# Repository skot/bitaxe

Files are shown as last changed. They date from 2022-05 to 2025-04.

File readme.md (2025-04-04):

# Bitaxe hardware repository has split into model specific repos and moved to [bitaxeorg](https://github.com/bitaxeorg)
```
Open Source is Intrinsic to Bitcoin
```
# The bitaxeUltra
bitaxe is a fully open source hardware Bitcoin ASIC miner. Ultra is the 3rd major revision of the bitaxe that now includes the BM1366 ASIC from the S19XP

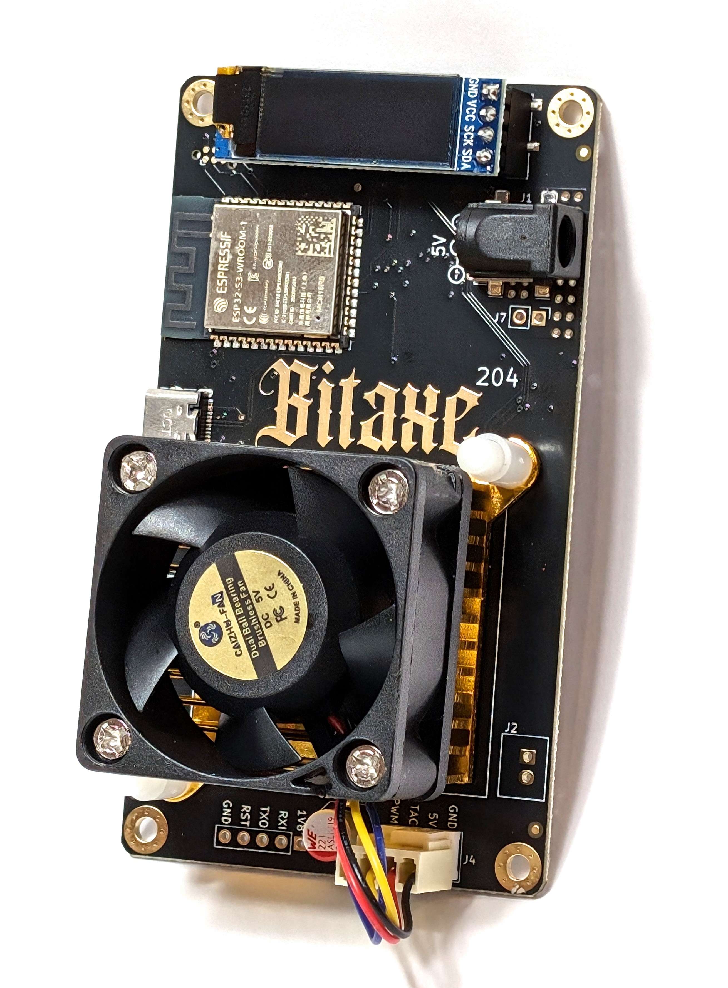
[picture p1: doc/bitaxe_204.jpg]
bitaxeUltra assembled


## Goals
- **Standalone**: can mine directly to your pool over WiFi. No External computer needed.
- **Embedded**: low cost, low maintenance, high availability, high reliability, low power.
- **ASIC**: based on the very, very efficient BM1366 from Bitmain.
- **Versatile**: solo/pool mining, autotune power/heat/efficiency.
- **Open Source**: All design files are provided.

## Features
- **ESP32-S3-WROOM-1** wifi microcontroller on board
- **TI TPS40305** buck regulator steps down the 5V input to power the BM1366
- **Maxim DS4432U+** current DAC digitally adjusts the BM1366 core voltage from 0.04V to 2.4V
- **TI INA260** power meter measures the input voltage and current of the miner
- **Microchip EMC2101** PWM controls the fan and monitors tach output. BM1366 doesn't support die temp, but we have it placed super close to the ASIC so we can use the internal temp feature.
- 0.91" **SSD1306 OLED** I2C Display Module 

## BM1366
- The BM1366 is a undocumented SHA256 mining ASIC from Bitmain. It's used in the Antminer S19XP and the S19k Pro
- Bitmain claims the BM1366 has 0.021J/GH efficiency
- The BM1366 is available (new) for around $15 each in small quantities.
- The BM1366 has a different footprint and pinout from the BM1397 and BM1387 in previous bitaxe.
- The BM1366 appears to roll more than just the nonce on the chip. This is great news, because it allows much longer serial chains of ASICs and new work doesn't need to be sent as often.

## Current Status
- Bitaxe Ultra 204 hardware has been verified and is working nicely!
- Be sure to check the [issues](https://github.com/skot/bitaxe/issues) for known bugs, reworks and errata.
- This is an _advanced_ build! You can do it, but if you're not looking for a project, it might be best to buy one pre-assembled from one of the many sellers.

## Hardware
- Order PCBs from your favorite PCB shop, like [JLCPCB](https://jlcpcb.com), [SeeedStudio](https://www.seeedstudio.com/fusion_pcb.html), or [PCBWay](https://www.pcbway.com)
    - Gerbers are in the `Manufacturing Files` dir. PCBs are 4-layer, 6mil trace/space and 0.3mm hole compatible. 1oz outer / 0.5oz inner layer thickness works well.
    - Make sure to order stencils too. These are the "paste" layers in the gerbers folder. one for top and one for bottom.
- All PCB parts except the ASIC are available from [DigiKey](https://www.digikey.com/en/products) and others. You can find Digikey part numbers on the DK tab of the BOM
- [BM1366 ASIC from NBTC on AliExpress](https://www.aliexpress.us/item/3256804709142138.html). I got the "AG" variant. Not really sure what the difference is -- "AL" works also.
- [40x40mm heatsink and 5V fan](https://www.aliexpress.com/item/2251832861666365.html) from a random AliExpress seller. The fans are crap, but the heatsinks are good. **make sure** to use a good quality thermal compound between the heatsink and ASIC!
- Upgrade your fan with the [Noctua NF-A4x20](https://www.amazon.com/Noctua-NF-A4x20-5V-PWM-Premium-Quality/dp/B071FNHVXN) 5V 4-Pin fan for a much more pleasant experience.
	- Get some longer mounting screws for the 20mm thick fan vs the 10mm thick fan that comes with the heatsink: [M3x25mm Flat Head Wood Self Tapping screws](https://www.amazon.com/dp/B08W5DQ23J)
- Supports 0.91" SSD1306-based I2C OLED Module. [Example Amazon seller](https://www.amazon.com/gp/product/B08ZY4YBHL)
- [KiCad 7](https://www.kicad.org) design files

## Software
- The [ESP-Miner](https://github.com/skot/ESP-Miner) firmware used for the BM1397-based bitaxe has been adapted for the BM1366 and the current main branch can support both.

## Cooling
- You **must** have active cooling on the bitaxe. 
- The Bitaxe has a connector for a 5V fan. 40x40mm fans work nicely with the suggested heatsink
- The fan connector uses the 4-pin standard:
	- 2 pins are for 5V power
	- pin 3 is fan speed sensing
	- pin 4 is fan speed control (PWM) 

## Power Supply Requirements
- **5V DC Only!** Anything else will damage the Bitaxe. Be careful and double-check your power supply is 5V. Many other voltage power supplies use the same connector.
- The Bitaxe needs 15W. Be aware that many power supplies _cannot_ deliver 5V at the listed power. It is best to pick an overrated power supply. 25W (5V, 5A) PSUs have been working well for people.
- The Bitaxe uses a 5.5x2.1mm, center-positive barrel jack.

### ESP32 Programming Requirements
- As of the bitaxeUltra, all ESP32 programming is done through a USB-C cable and connector on the bitaxe. See [ESP-Miner](https://github.com/skot/ESP-Miner) for more details.

## Building
- Check out [building.md](building.md) for PCB ordering tips
- Check out [assembly.md](assembly.md) for assembly tips

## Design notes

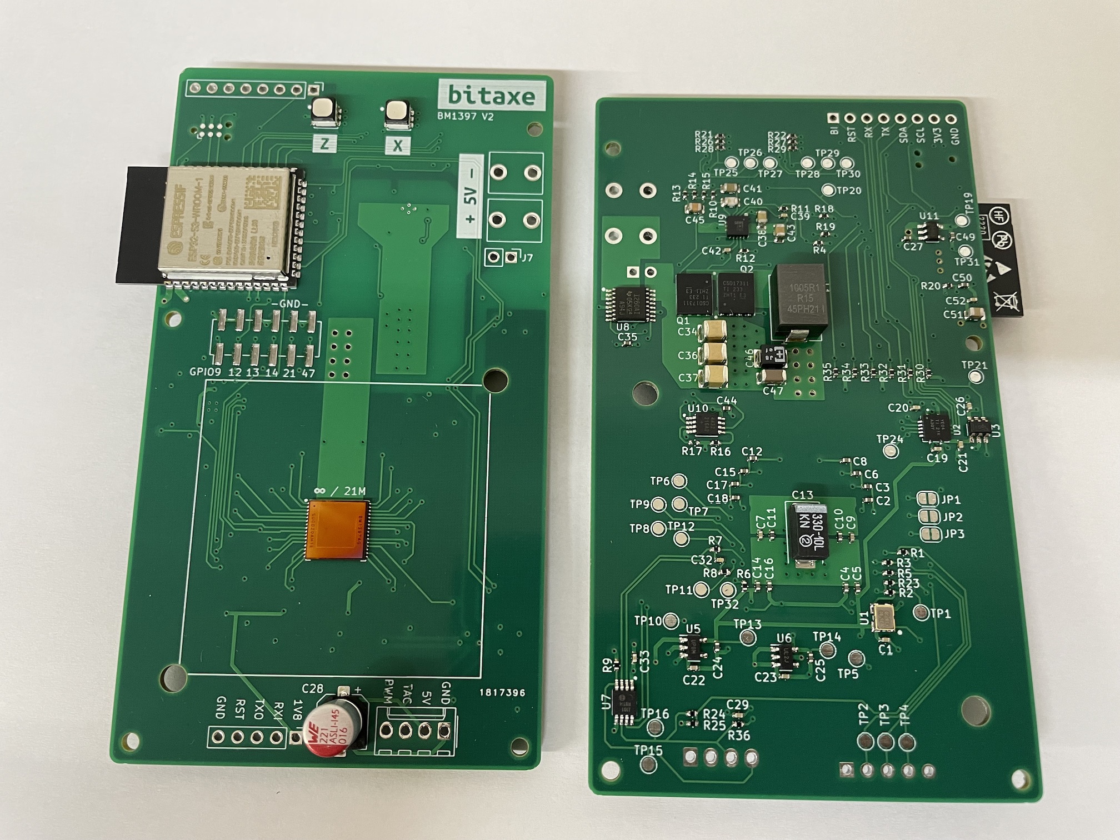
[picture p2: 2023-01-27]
doc/v2_both_sides.jpg

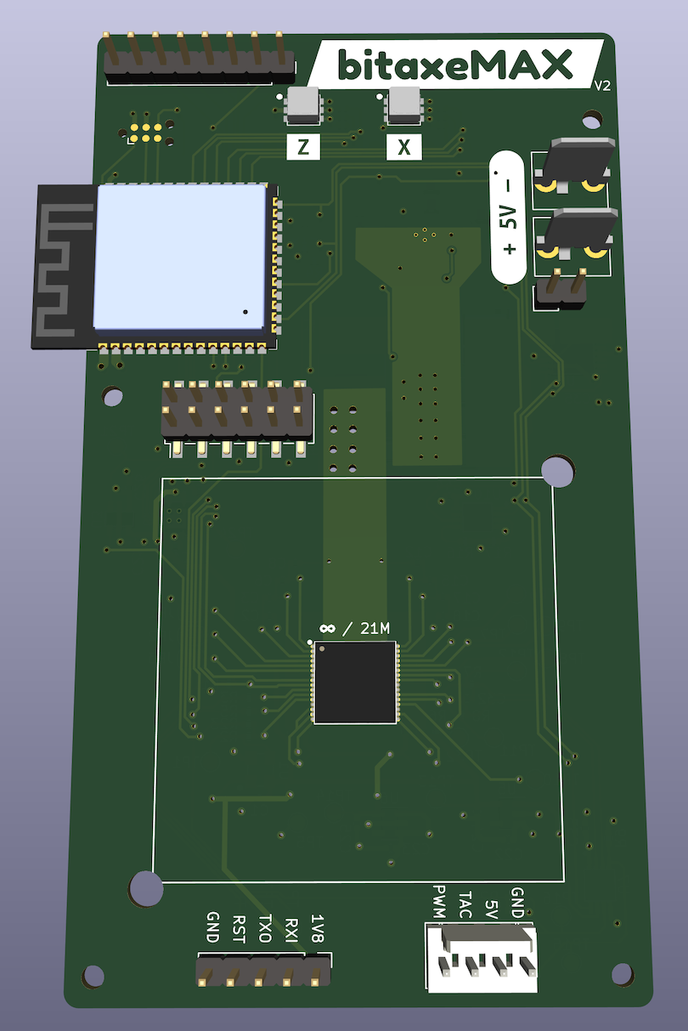
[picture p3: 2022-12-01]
doc/front.png

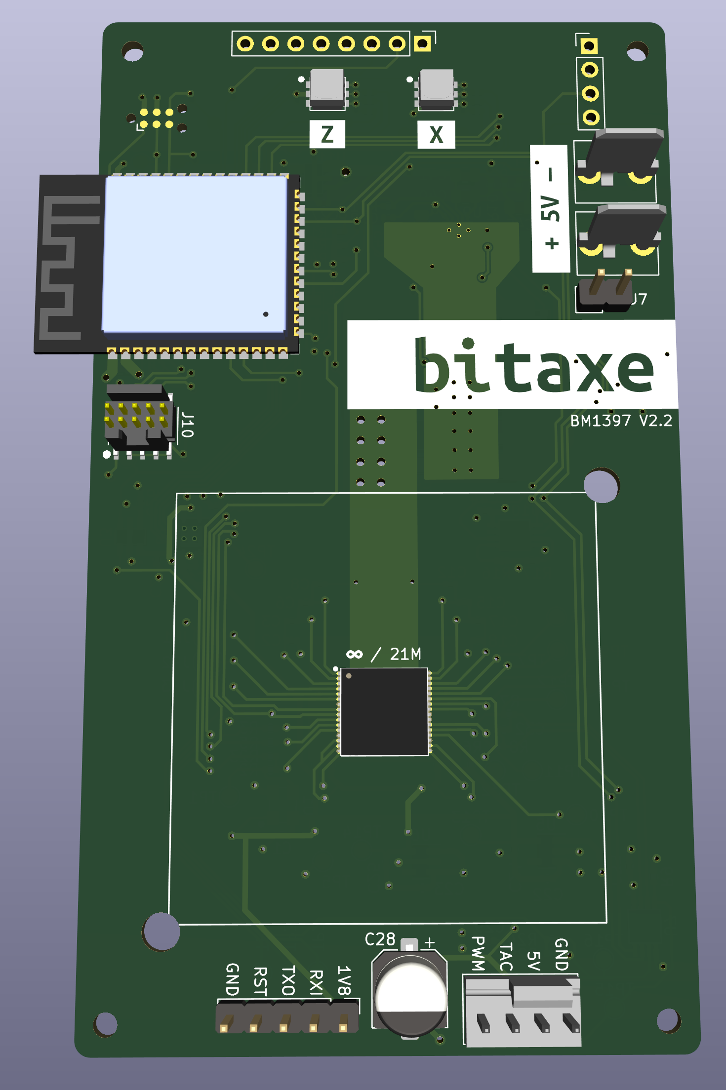
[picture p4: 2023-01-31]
doc/render.png

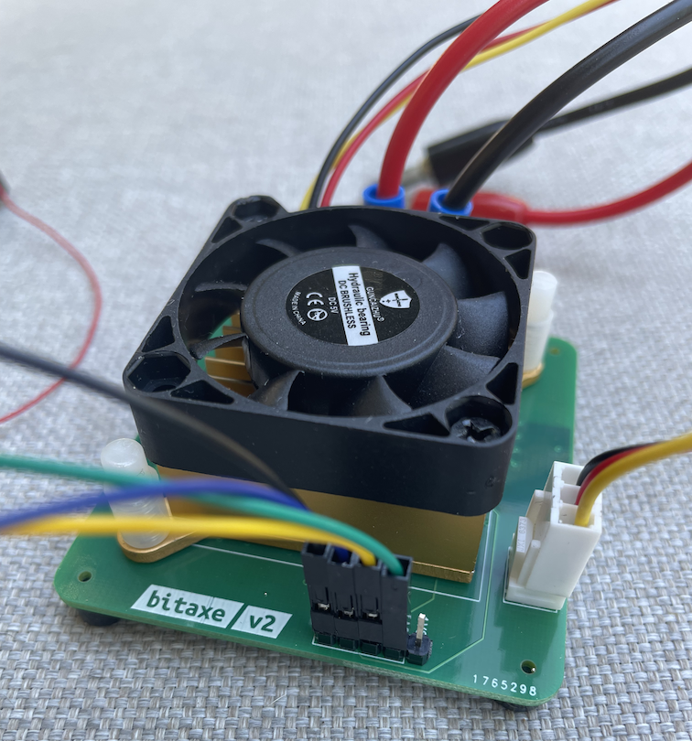
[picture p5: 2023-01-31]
doc/bitaxe.png

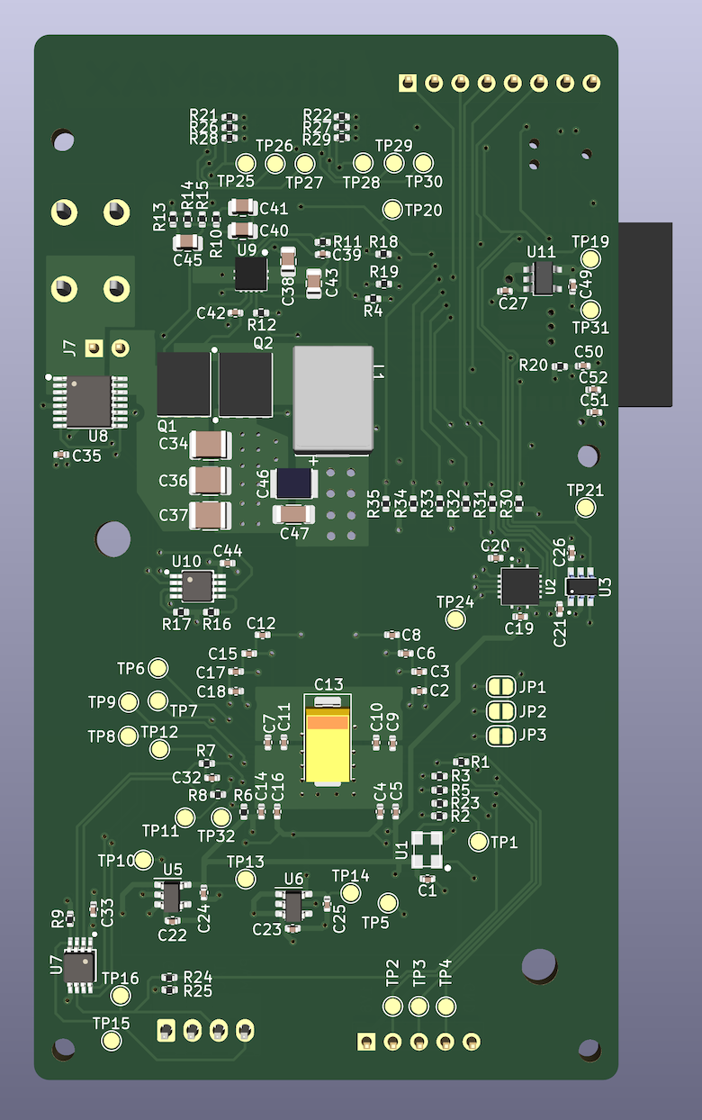
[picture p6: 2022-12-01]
doc/back.png

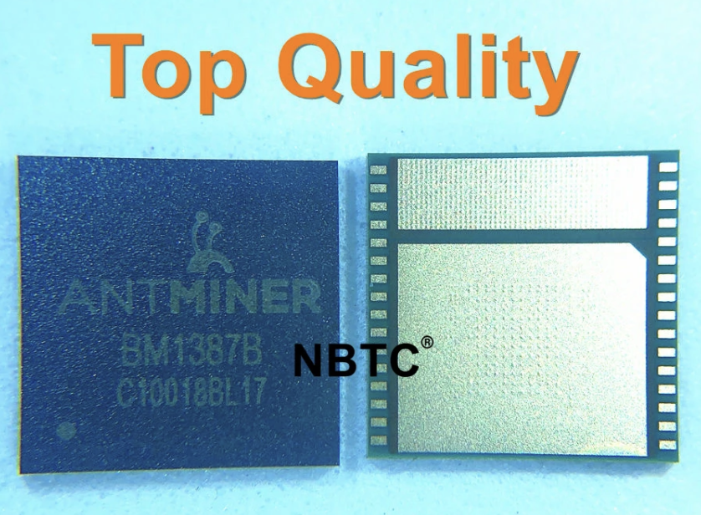
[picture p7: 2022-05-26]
doc/bm1387.png

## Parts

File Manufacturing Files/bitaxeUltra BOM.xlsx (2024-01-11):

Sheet: BOM
Qty | Ref Des | Value | DK | PARTNO | DNP
9 | C1, C7, C9, C19, C20, C29, C33, C42, C52 | 0.1uF | 1292-1639-1-ND | 0402X104K100CT
23 | C2, C3, C4, C5, C6, C8, C10, C11, C12, C14, C15, C16, C17, C18, C21, C22, C23, C24, C25, C27, C35, C44, C49 | 1uF | 587-5514-1-ND | EMK105BJ105MV-F
1 | C13 | 330uF | 718-1028-1-ND | 293D337X9010E2TE3
1 | C28 | 220uF | 732-8422-1-ND | 865080345012
2 | C30, C31 | 6.8pF | 399-C0402C689C5GAC7867CT-ND | C0402C689C5GAC7867
3 | C34, C36, C37 | 47uF | 490-6539-1-ND | GRM32ER61C476KE15L
1 | C38 | 1uF | 1276-6471-1-ND | CL21B105KOFNNNG
1 | C39 | 3.3nF | 1276-1552-1-ND | CL05B332KB5NNNC
1 | C40 | 180pF | 311-1114-1-ND | CC0805JRNPO9BN181
1 | C41 | 1.5nF | 311-1128-1-ND | CC0805KRX7R9BB152
2 | C43, C51 | 10uF | 1276-1096-1-ND | CL21A106KOQNNNE
1 | C45 | 470pF | 1292-1580-1-ND | 0805B471K500CT
1 | C46 | 220uF | P16200CT-ND | 2R5TPE220MAFB
1 | C47 | 100uF | 445-6008-1-ND | C3216X5R0J107M160AB
1 | D1 | SS310 | SK310A-LTPMSCT-ND | SK310A-LTP
1 | J1 | 54-00164 | 839-54-00164CT-ND | 54-00164
1 | J2 | Conn_01x02 | 455-B2B-XH-A-ND | B2B-XH-A
1 | J4 | Conn_01x04 | WM4330-ND | 0470531000
1 | J8 | USB_C_Receptacle_USB2.0 | 2073-USB4105-GF-ACT-ND | USB4105-GF-A
1 | L1 | 150nH | 513-1568-1-ND | FP1005R1-R15-R
2 | Q1, Q2 | CSD17311Q5 | 296-27625-1-ND | CSD17311Q5
1 | Q4 | 2N7002K | 2N7002KWCT-ND | 2N7002KW
5 | R1, R4, R6, R7, R9 | 10k | 311-10KJRCT-ND | RC0402JR-0710KL
1 | R2 | 5.6k | 13-RC0402FR-135K6LCT-ND | RC0402FR-135K6L
2 | R3, R5 | 5.1k | RMCF0402JT5K10CT-ND | RMCF0402JT5K10
1 | R8 | 1M | 311-1.00MLRCT-ND | RC0402FR-071ML
1 | R10 | 3.83k | 311-3.83KLRCT-ND | RC0402FR-073K83L
1 | R12 | 4.12k | RMCF0402FT4K12CT-ND | RMCF0402FT4K12
1 | R13 | 1.33k | 311-1.33KLRCT-ND | RC0402FR-071K33L
1 | R14 | 4.99k | 311-4.99KLRCT-ND | RC0402FR-074K99L
1 | R15 | 3.32k | 311-3.32KLRCT-ND | RC0402FR-073K32L
1 | R16 | 80.6k | 311-80.6KLRCT-ND | RC0402FR-0780K6L
2 | SW1, SW2 | GT-TC029B-H025-L1N | 2449-CS1213AGF260CT-ND | CS1213AGF260
1 | U1 | 25MHz | 1908-O250-JO32-B-1V3-1-T1-LFCT-ND | O 25,0-JO32-B-1V3-1-T1-LF
1 | U2 | TXB0104RGYR | 296-21930-1-ND | TXB0104RGYR
1 | U5 | MCP1824T-1802E | MCP1824T-1802E/OTCT-ND | MCP1824T-1802E/OT
1 | U6 | MCP1824T-0802E | MCP1824T-0802E/OTCT-ND | MCP1824T-0802E/OT
1 | U7 | EMC2101 | EMC2101-R-ACZL-CT-ND | EMC2101-R-ACZL-TR
1 | U8 | INA260 | 296-45218-5-ND | INA260AIPW
1 | U9 | TPS40305 | 296-37445-1-ND | TPS40305DRCR
1 | U10 | DS4432U+ | DS4432U+-ND | DS4432U+
1 | U11 | RT9080-33GJ5 | 1028-1509-1-ND | RT9080-33GJ5
1 | U12 | ESP32-S3-WROOM-1 | 1965-ESP32-S3-WROOM-1-N16R8CT-ND | ESP32-S3-WROOM-1-N16R8
1 | U14 | BM1366_mode1
1 | Y1 | 32.768kHz | 728-1074-1-ND | SC32S-7PF20PPM
1 | J9 | Conn_01x04 | S5596-ND | NPTC041KFXC-RC

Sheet: DK Order
Qty | Ref Des | DK
9 | C1, C7, C9, C19, C20, C29, C33, C42, C52 | 1292-1639-1-ND
23 | C2, C3, C4, C5, C6, C8, C10, C11, C12, C14, C15, C16, C17, C18, C21, C22, C23, C24, C25, C27, C35, C44, C49 | 587-5514-1-ND
1 | C13 | 718-1028-1-ND
1 | C28 | 732-8422-1-ND
2 | C30, C31 | 399-C0402C689C5GAC7867CT-ND
3 | C34, C36, C37 | 490-6539-1-ND
1 | C38 | 1276-6471-1-ND
1 | C39 | 1276-1552-1-ND
1 | C40 | 311-1114-1-ND
1 | C41 | 311-1128-1-ND
2 | C43, C51 | 1276-1096-1-ND
1 | C45 | 1292-1580-1-ND
1 | C46 | P16200CT-ND
1 | C47 | 445-6008-1-ND
1 | D1 | SK310A-LTPMSCT-ND
1 | J1 | 839-54-00164CT-ND
1 | J2 | 455-B2B-XH-A-ND
1 | J4 | WM4330-ND
1 | J8 | 2073-USB4105-GF-ACT-ND
1 | L1 | 513-1568-1-ND
2 | Q1, Q2 | 296-27625-1-ND
1 | Q4 | 2N7002KWCT-ND
5 | R1, R4, R6, R7, R9 | 311-10KJRCT-ND
1 | R2 | 13-RC0402FR-135K6LCT-ND
2 | R3, R5 | RMCF0402JT5K10CT-ND
1 | R8 | 311-1.00MLRCT-ND
1 | R10 | 311-3.83KLRCT-ND
1 | R12 | RMCF0402FT4K12CT-ND
1 | R13 | 311-1.33KLRCT-ND
1 | R14 | 311-4.99KLRCT-ND
1 | R15 | 311-3.32KLRCT-ND
1 | R16 | 311-80.6KLRCT-ND
2 | SW1, SW2 | 2449-CS1213AGF260CT-ND
1 | U1 | 1908-O250-JO32-B-1V3-1-T1-LFCT-ND
1 | U2 | 296-21930-1-ND
1 | U5 | MCP1824T-1802E/OTCT-ND
1 | U6 | MCP1824T-0802E/OTCT-ND
1 | U7 | EMC2101-R-ACZL-CT-ND
1 | U8 | 296-45218-5-ND
1 | U9 | 296-37445-1-ND
1 | U10 | DS4432U+-ND
1 | U11 | 1028-1509-1-ND
1 | U12 | 1965-ESP32-S3-WROOM-1-N16R8CT-ND
1 | U14
1 | Y1 | 728-1074-1-ND
1 | J9 | S5596-ND

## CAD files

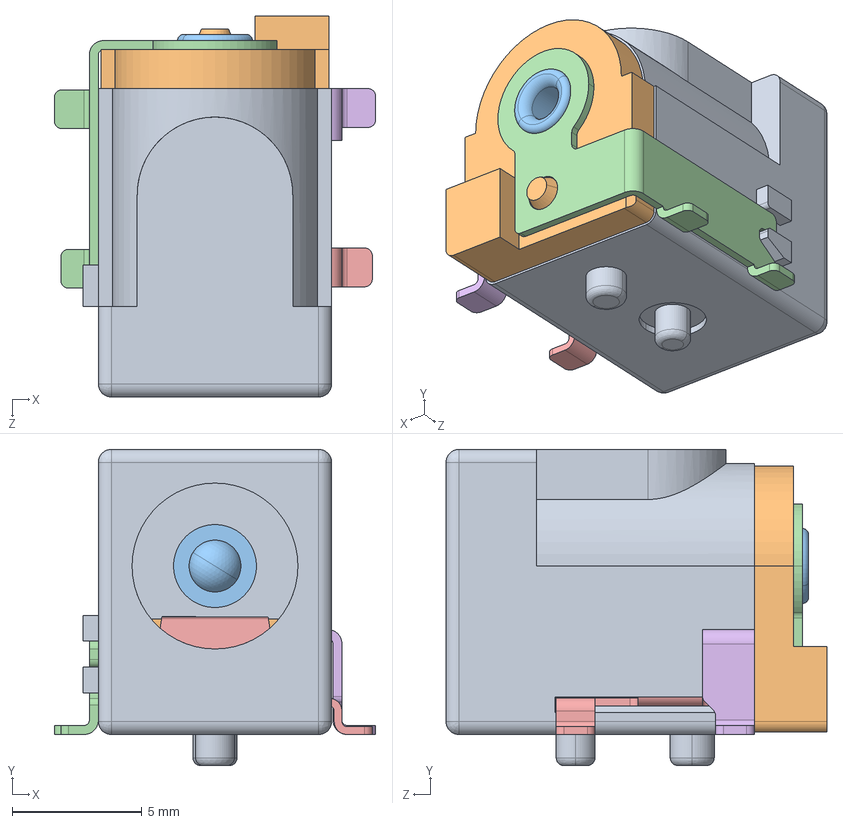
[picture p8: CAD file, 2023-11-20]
3d/54-00164.STEP
12.4 x 12.2 x 14.7 mm
54-00164_shell
54-00164_insulator
54-00164_center
54-00164_center contact
54-00164_spring contact
54-00164_shell contact

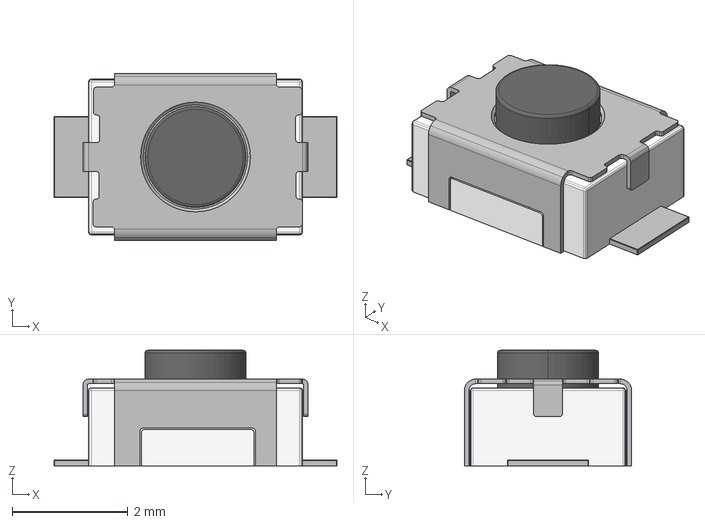
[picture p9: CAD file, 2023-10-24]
3d/CS1213AG-tr.stp
4.90 x 2.90 x 2.00 mm

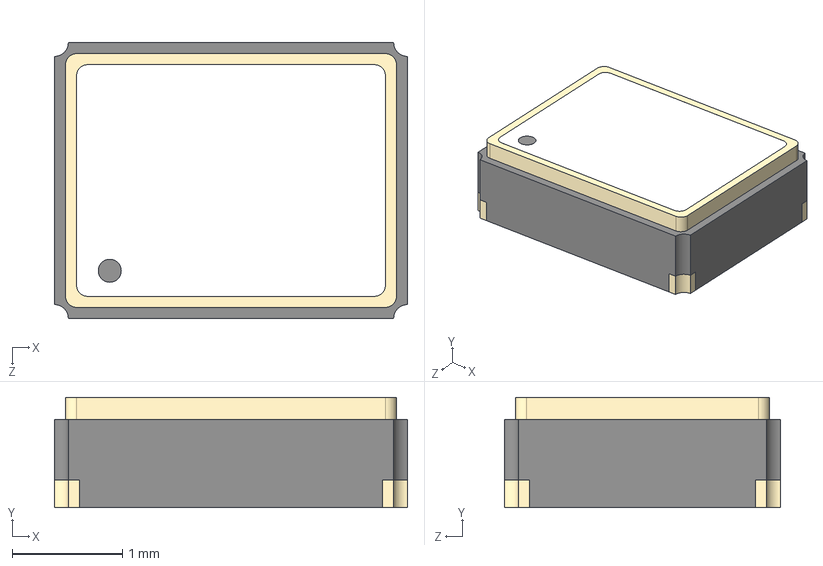
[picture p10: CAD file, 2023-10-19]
3d/oscillator3.2x2.5.step
3.20 x 1.00 x 2.50 mm

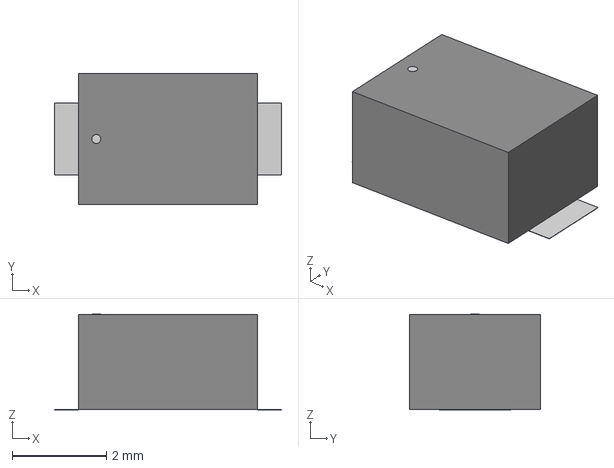
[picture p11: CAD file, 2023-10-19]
3d/SW_CS1213AGF260_CRS.step
4.83 x 2.79 x 2.04 mm

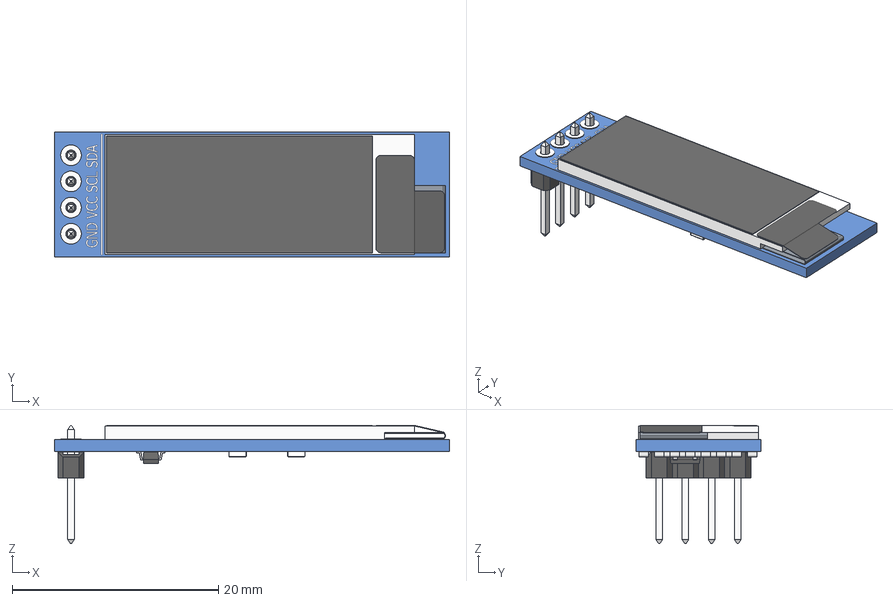
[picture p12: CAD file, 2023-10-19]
3d/OLED_0.91_128x32.stp
38.3 x 12.1 x 11.5 mm
OLED_0.91_128x32
Pin Header 4 x 1 TH 2.54mm Pitch
RESC-0603 x 13
2SD0601A

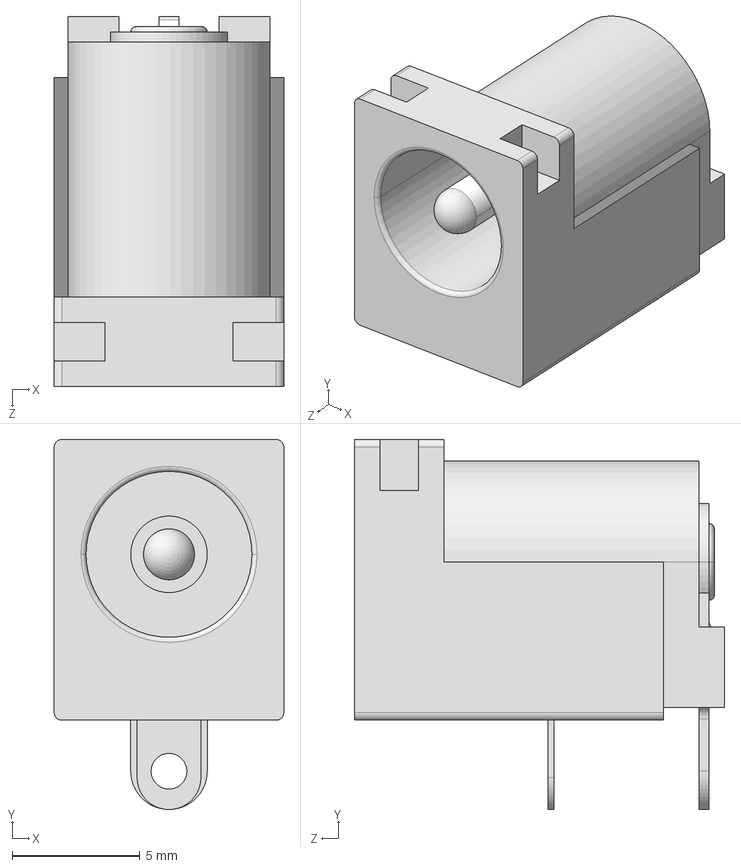
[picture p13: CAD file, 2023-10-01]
3d/CUI_DEVICES_PJ-037AH.step
9.00 x 14.5 x 14.5 mm

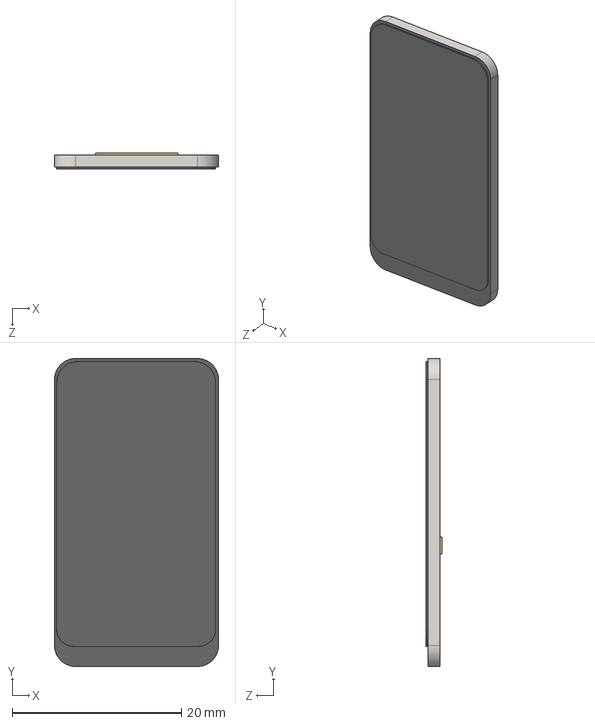
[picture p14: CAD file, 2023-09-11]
3d/DISST7789-176x320.STEP
19.4 x 36.4 x 1.86 mm

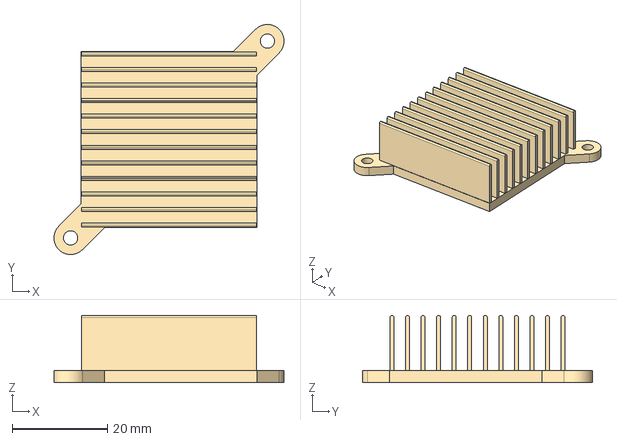
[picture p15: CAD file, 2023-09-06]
3d/Bitaxe_Heatsink.step
48.4 x 48.4 x 14.1 mm

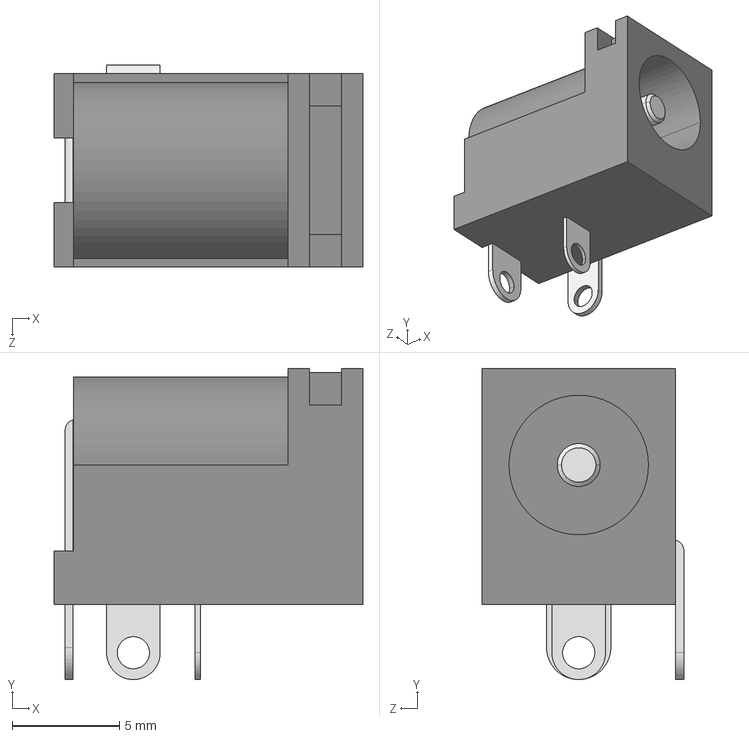
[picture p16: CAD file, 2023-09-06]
3d/CUI_DEVICES_PJ-002AH.step
14.4 x 14.5 x 9.40 mm

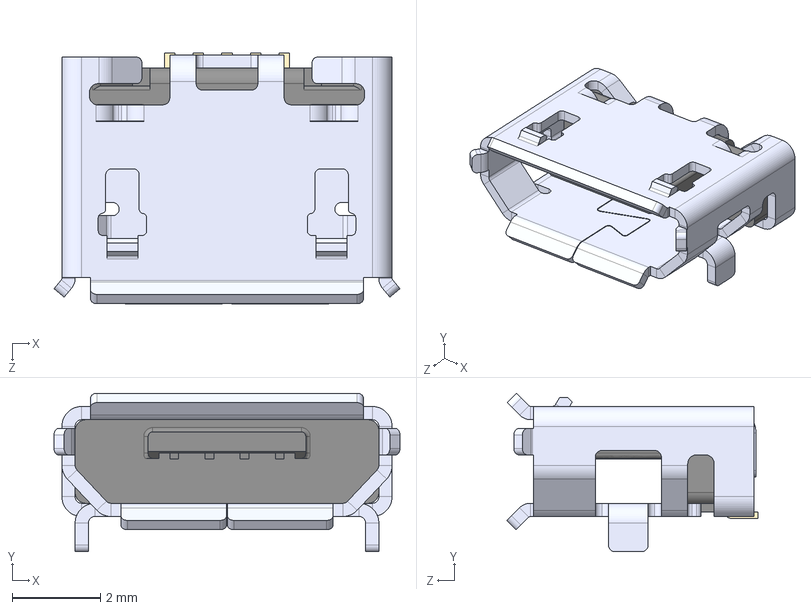
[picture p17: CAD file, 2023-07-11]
3d/USB_10118193-0001LF.STEP
7.86 x 3.60 x 5.71 mm

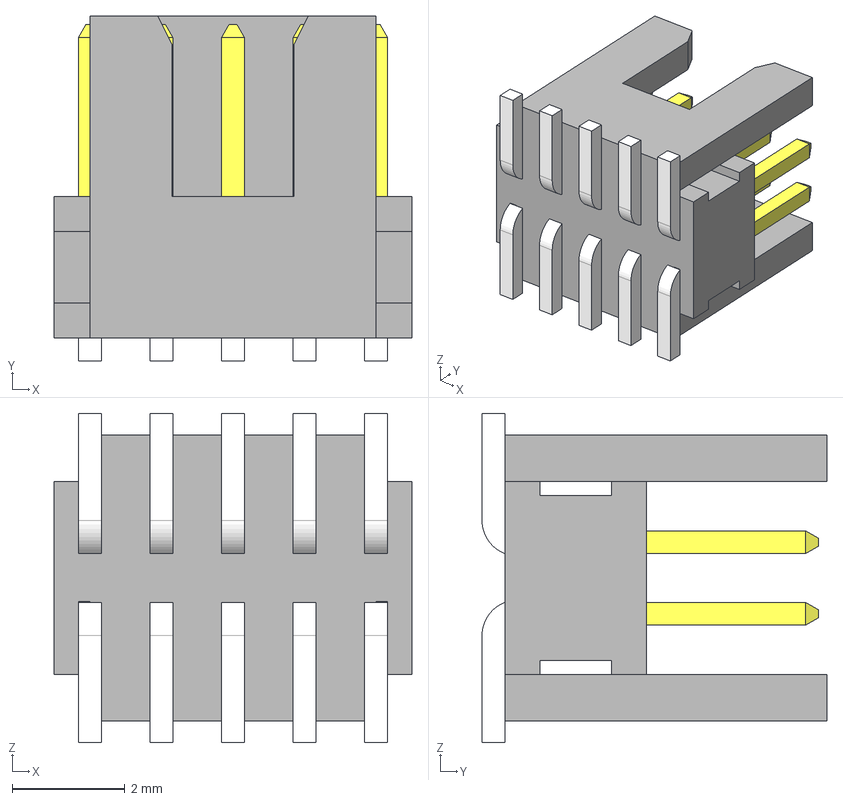
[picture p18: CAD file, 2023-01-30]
3d/FTSH-105-01-F-DV-K.stp
6.35 x 6.12 x 5.84 mm
FTSH-105-01-F-DV-K_pins2
FTSH-105-01-F-DV-K_pins1
FTSH-105-01-F-DV-K_body

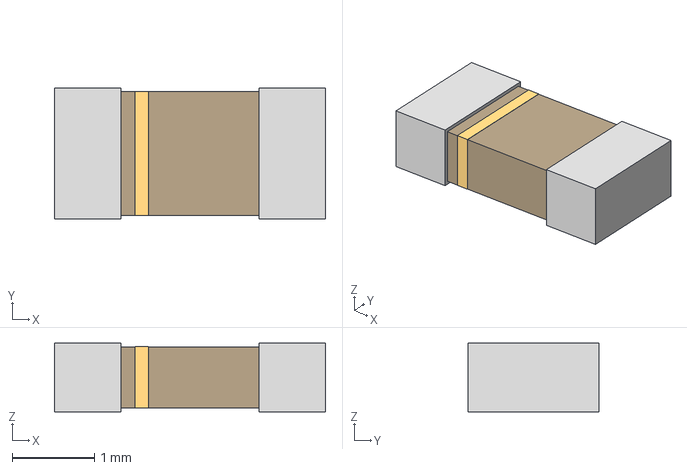
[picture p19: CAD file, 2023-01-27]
3d/XTAL_SC32S-7PF20PPM_EPS.step
3.30 x 1.60 x 0.838 mm

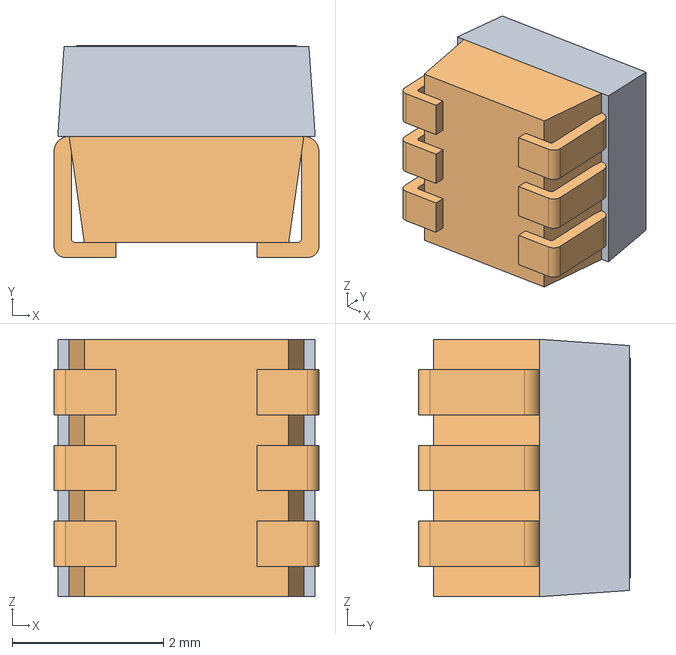
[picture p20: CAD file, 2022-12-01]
3d/Cree_PLCC6.stp
3.50 x 2.80 x 3.40 mm
CORPS-DPLACER_COPI0001_1
CORPS-DPLACER_COPI0002_1

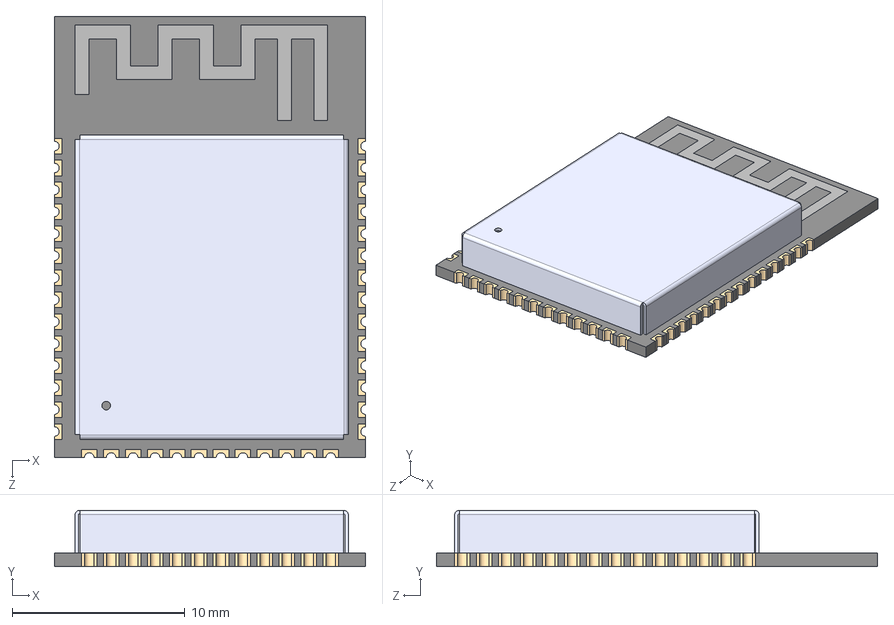
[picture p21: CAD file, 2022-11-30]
3d/ESP32-S3-WROOM-1-N8R2--3DModel-STEP-56544.STEP
18.0 x 3.25 x 25.5 mm

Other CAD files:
3d/TSOT-23-5_RIT.step
3d/PLCC6_LED_3_5X3_4X2_8_CRW.step
3d/SN74AXC1T45DBVR.STEP
3d/TXB0104RGYR.STEP
3d/21-0164B_L622-1_MXM.step
3d/2R5TPE220MAFB.step
3d/470531000.stp
3d/CX3225SB16000H0FLJCC.STEP
3d/DQG0008A.stp
3d/DQH0008A.stp
3d/DRC0010J.stp
3d/DRL0006A.stp
3d/FP1006V2-R.STEP
3d/IHLP2020CZ.step
3d/SMV_z90.stp
3d/SOT-23-5_M5_MCH.step
3d/ST-4ETB2k_(202).stp
3d/XRCGB27M120F3M10R0_MUR.step
3d/c-63862-1-r-3d.stp

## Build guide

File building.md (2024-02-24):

# Building PCBs

In order to get PCBs made, you usually need to provide them with the following files;

- Gerbers
- Drill Files

Additionally if you want to have a shop assemble the boards for you, you’ll also need to provide;

- Bill of Materials (BOM)
- Centroid file (XY)

### Generating Gerbers and Drill Files

Gerbers are a set of files in a standard format that allow a PCB manufacturer to build the PCB. Usually there is one gerber file for each layer of a PCB. A Gerber file can represent a wide variety of different layer types;

- Copper layer
- Silkscreen Layer
- Soldermask layer
- Board outline
- Drills (Okay, this is actually not a gerber, but your PCB house will definitely need it)

Any* PCB CAD software will allow you to generate gerbers. We use [KiCad](https://www.kicad.org) because it is open source, free, and *awesome*. Here is how to generate gerbers in KiCad v6;

1. Open up the design in KiCad and switch to the PCB board editor view (ie not the schematic). Some people call this pcbnew.
2. Choose File → Fabrication Outputs → Gerbers (.gbr)…
3. Pick the right options for what your PCB board house expects. Here is what I use;

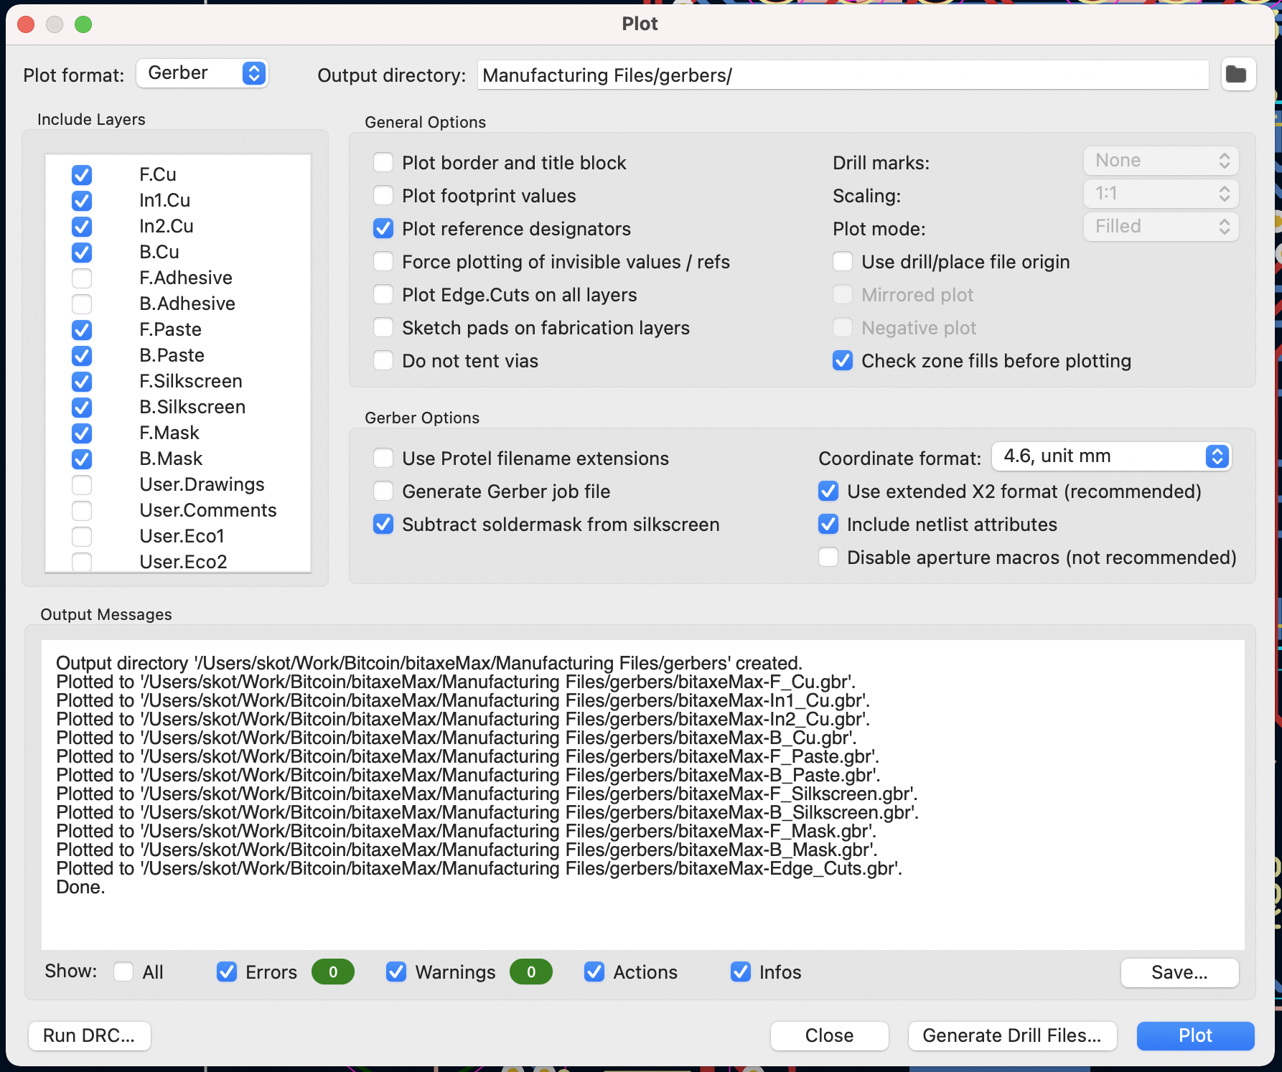
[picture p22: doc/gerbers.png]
Gerber Plot Window


Make sure you have these “Include Layers” checked;

- **F.Cu** → Front copper
- **In1.Cu** → Inner layer 1 Copper
- **In2.Cu** → Inner layer 2 Copper
- **B.Cu** → Back copper
- **F.Paste** → Front Paste. Note: this is used to make a solder paste stencil. This is optional. Many PCB houses will let you order stencils as a separate step. use these gerbers for ordering a stencil
- **B.Paste** → Back paste. see note above
- **F.Silkscreen** → Front Silkscreen. sometimes this is called the Legend
- **B.Silkscreen** → Back Silkscreen. sometimes this is called the Legend of Zelda
- **F.Mask** → Front soldermask
- **B.Mask** → Back soldermask
- **Edge.Cuts** → The board outline. This defines the shape the PCB is cut to.

1. Next you’ll want to generate the drill files. Click that button in the lower right corner of the “Plot” screen from above.
2. Generate the drill files according to your PCB house specs. Here are the options I use;

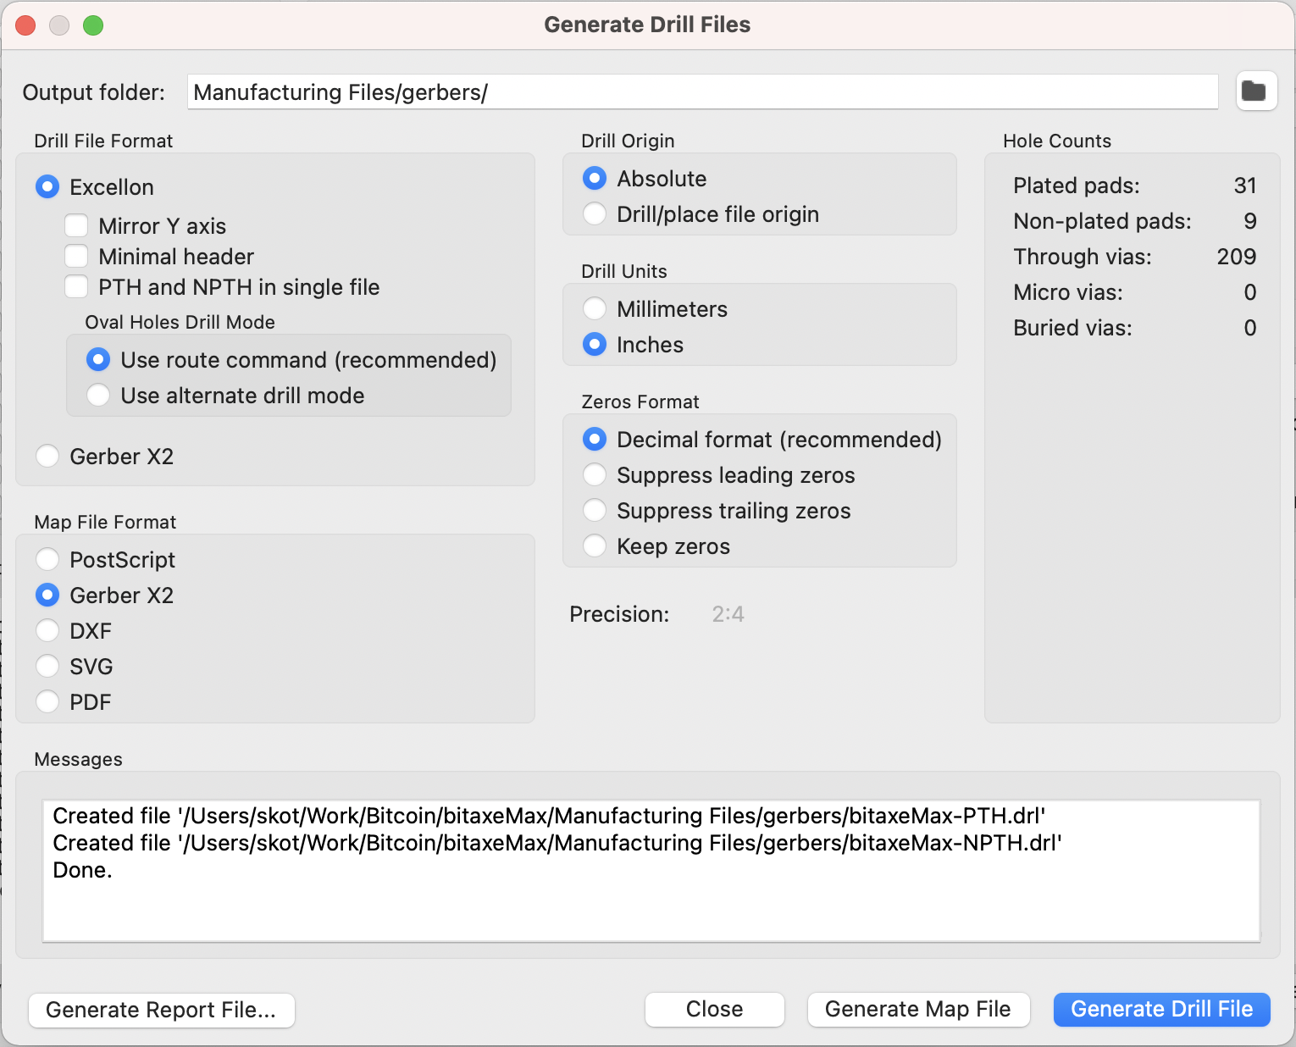
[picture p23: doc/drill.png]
Drill Files Window


That’s it! Take all of those generated files and give them to your PCB house. If you’re ordering stencils (which you should!), pull out `-F_Paste.gbr` and `-B_Paste.gbr` and send those to the right place. Paste gerbers are not needed to manufacture a PCB.

### Generating PCBA Manufacturing files

Generally speaking, PCBA shops are going to want a file telling them the exact placement of all the components. This is referred to as "Centroid file", "Component Placement (.pos)" and "XY file". 
You can generate this in KiCad by switching to PCB Editor and choosing `File` -> `Fabrication Outputs` -> `Component Placement (.pos)`. 
Check with your PCBA shop to see exactly how they want this file formatted.

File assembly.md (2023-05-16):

- Get a convection toaster oven. Nothing fancy, it just has a fan inside for more even heating. Never use this oven for food.
  - [BLACK+DECKER TO3250XSB 8-Slice Extra Wide Convection Countertop Toaster Oven, Includes Bake Pan, Broil Rack & Toasting Rack, Stainless Steel/Black](https://www.amazon.com/BLACK-DECKER-TO3250XSB-Convection-Countertop/dp/B00LU2I428)
- Get a thermocouple thermometer. Make sure the probe and probe jacket can go to ~300C
  - [Digital Thermocouple Temperature Thermometer, PEAKMETER PM6501 K Type LCD Thermometer Testing Tool Celsius and Fahrenheit](https://www.amazon.com/Thermocouple-Temperature-Thermometer-PEAKMETER-Fahrenheit/dp/B08L11MMFM)
- Use Sn63/Pb37 no-clean, leaded, solder paste. Keep it in the refrigerator so it's nice and cold before you stencil it. (obvs don't get it near your food). Wash your hands well after.
  - [Chip Quik SMD291AX50T3 Solder Paste in jar 50g (T3) Sn63/Pb37 no clean](https://www.amazon.com/gp/product/B07BH5LP5G)
- Take your time to get the paste stenciled right. Don't be afraid to wipe it off with IPA and try again. The paste stencils better when it's cold.
- Use tweezers to put all of the parts on the pasted board. I like the curved Aven Technik 7-SA Tweezers. I have also been known to wear a dorky magnifier headset.
  - [Aven 18072ARS 7-SA Style Artis Tweezer, Black with Yellow Print](https://www.amazon.com/Aven-18072ARS-Style-Tweezer-Yellow/dp/B01D4R1OXW)
  - [Headband Magnifier Hands Free Jeweler Loupe Head Mount Magnifying Headset Visor Double Optical Glass 4 Replaceable Lenses for Reading,Repair(1.5X,2.0X,2.5X,3.5X)](https://www.amazon.com/Headband-Magnifier-Jeweler-Magnifying-Replaceable/dp/B08RYVH7DL)
- Put the board(s) in the toaster oven. I usually put them right on the wire rack, which is in the metal tray.
- Put the thermocouple inside the toaster oven. Close the door on the thermocouple wire so that it holds the end right above the PCB, inside the oven.
- Turn the oven on convection bake, medium setting. The convection fan in the toaster oven helps keep the temperature even through out the inside of the oven.
- Once the temp (as read off the thermocouple thermometer) gets to 140C, turn down the oven heat and try and keep it at 140-150C for 2 minutes. Open the door a little if it's getting to hot. This is the "Soak" phase
- After two minutes, turn the heat to high
- Once the temp reaches 200C start a timer for 30 seconds. Keep the temp between 200 and 220C for this phase. Usually you don't need to do anything. This is the "Reflow" phase. You should see all of the paste melt.
- After 30 seconds, turn off the toaster oven. open the door.
- Let the boards cool for a bit in the oven with the door open.
- Once cool to touch, inspect the boards with a microscope for dry pads and/or bridges. Depending on how well you did with stenciling there may be a few, especially on QFP packages. QFNs sometimes too. Fix these up with paste flux, solder braid and your soldering iron.
- If you have parts on both sides of the board, it's fine to just repeat the steps on the second side. The surface tension of the solder almost always keeps the parts from falling off while they are getting reflowed upside down. When you reflow the second side, make a little stand out of metal to keep the bottom side parts off the wire rack in the toaster oven.

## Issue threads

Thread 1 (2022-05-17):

silkscreen of C17 and C18 has polarity backwards

skot, 2022-05-17:
flip the silkscreen

skot, 2022-06-15:
Ack, this was correct in v1, so now it's backwards in v2 because of 6d5e3a8. The band on C17 and C18 mark the **positive** side of the capacitor.

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

barnix2001, 2023-01-08:
Hi! Bitaxe is a great project. Something is wrong about JTAG for ESP32-S3-WROOM-1.
Your JTAG on PCB is: GPIO9, GPIO12, GPIO13, GPIO14, GPIO21, GPIO47
JTAG for ESP32-S3-WROOM-1 in doc is: IO42,IO41,IO40,IO39

Closed 2022-11-25.

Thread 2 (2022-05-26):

Heatsink mounting holes are not quite correct

skot, 2022-05-26:
they need to be spaced a little further apart.

robomaniac, 2022-06-10:
You could have one of those holes slotted.

skot, 2022-06-10:
When I first laid out this board the heatsinks hadn't arrived from China yet. They're here now, and it looks like the holes should be 58.5mm apart. (kinda random)

skot, 2022-06-29:
the 58.5mm spaced holes work like a charm.

Closed 2022-06-29.

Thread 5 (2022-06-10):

BM1387 footprint pin pitch is wrong!!

skot, 2022-06-10:
rrrrrg. the pin pitch is wrong. this isn't going to work!

skot, 2022-06-11:
Switch the BM1387 pin pitch to 0.48mm in f5b4fd9. Hopefully that does it!

robomaniac, 2022-06-12:
Have you compare your footprint with this design?

https://www.pcbway.com/project/shareproject/PCB_for_Asic_BM1387__1397_.html

skot, 2022-06-13:
Maybe my gerber measuring isn't so accurate but it looks like some pins are spaced 0.5mm and some 0.46mm?

skot, 2022-06-13:
When I measure my gerbers, the tool (Cuprum) says 0.48mm for all pins. I'm not sure what's going on with this pcbway design.

robomaniac, 2022-06-13:
I just check with my gerber viewer and you are right, I also have values ranging from 0.46 to 0.5mm.
0.48mm is right in the ~middle 😅

skot, 2022-06-13:
sidehack on the bitcointalk.org forums (the guy who makes the Newpac USB miner) says he eventually landed on 0.475mm pitch.
https://bitcointalk.org/index.php?topic=5400851.msg60335480#msg60335480

skot, 2022-06-29:
Got the V2 boards back with the 0.48mm pitch. It's working well!

Closed 2022-06-29.

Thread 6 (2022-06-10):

core voltage pin headers are too small

skot, 2022-06-10:
The VIN pin headers used for powering the BM1387 core are a little too small and cause a pretty real voltage drop. need to come up with something different.

maybe screw terminals?

robomaniac, 2022-06-10:
Hey
This is Jerome from Reddit. Have a look at redcube from Würth Elektronik
https://www.digikey.ca/short/9q0wpdb3

There is other alternatives. On Würth website they give footprint for major software. Not sure about kicad.

Or even these but the circle one
https://www.digikey.ca/short/m05zbwz8

Big pad right underneath. You need screw and nut. Maybe washer and lock nut too

skot, 2022-06-10:
@robomaniac That's an excellent idea. I'll switch the VIN pins to one of those "spade terminal" style connectors today. I've got to spin these boards anyways for the pin pitch issue #5

skot, 2022-06-11:
I switched to these slotted terminals (also called spade). I think they are pretty common on industrial equipment. They're also cheap and in-stock.
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

skot, 2022-06-29:
The big spade connectors are working well in V2

Closed 2022-06-29.

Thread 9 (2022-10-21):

oscillator enable pin needs to be pulled high

skot, 2022-10-21:
U2 is the 25MHz oscillator. It needs pin 1, "e/d" to be pulled high to 1.8V. The data sheet of course doesn't mention this. Thanks alot Jauch!

skot, 2022-10-21:
The unfortunately named oscillator; [O 25,0-JO32-B-1V3-1-T1-LF](https://www.jauch.com/downloadfile/5ef1edcfb8e2f73163c8ce8009ef659d1/jo32-1.8-3.3v.pdf)

skot, 2022-10-25:
If you're working on R1 max boards, putting a jumper between TP1 and TP10 will do the trick.
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

Closed 2022-11-25.

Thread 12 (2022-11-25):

No protection on 5V input

skot, 2022-11-25:
the 5V input powers a number of things on the board. Should it be protected somehow?

skot, 2022-11-27:
Maybe something like a PolyZen fuse; https://www.littelfuse.com/media?itemid=f3e02f71-8329-4601-bbc8-e19318fb6c9f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

robomaniac, 2022-11-28:
if you don't protect Vin, why protect 5V?

5V is to get 1.8V and 0.8V and then power the fan. You could protect the fan only, a PTC (Resettable Fuses) right before J4. So if someone short the J4, the fuse will trigger.

Is that really necessary? it's rabbit hole, you can add protection TVS diode (ESD protection diode) on each input, TX, RX, etc.
What you could do is add them to schematic and let the user populated them on the PCB. Place them as close to the connector, not the chip. You want to catch the ESD way before it reach the IC. Where the static discharge will be applied, aka touching with finger the J4 connector or serial port J3 of the MAX.

skot, 2022-11-28:
this issue is in regards to the new `max_v2` branch. In this new schematic VIN is 5V and it powers everything;
- 5V is switch-mode regulated down to be the core voltage for the BM1397
- 5V is LDO regulated to 3V3 for the ESP32 and some other sensors
- 5V is regulated down to 1V8 and 0V8 like you say for the IO voltages.
- 5V powers the fan

BitMaker-hub, 2023-04-02:
Hi Skot, for me is a must to use TVS diodes and PTC fuses.
This could help a lot. There are 3A or 4A 1206 rearmable fuses really cheap.

shufps, 2023-10-23:
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

On my HAT I used this. But I also used +12V as input because 12V/3A power supplies are easier to get.

If I didn't get +5V from the Pi, I would use 12V regardless and add a 5V buck because it only has advantages.

shufps, 2023-10-23:
> this looks interesting... does D1 actually get you reverse polarity protection?
>
> @shufps are you on the OSMU discord? it might be easier to talk there. https://discord.gg/GzAg8GaT

:wave: I contacted you on discord :blush:

skot, 2024-04-25:
Maybe the [TPS25924](https://www.ti.com/lit/ds/symlink/tps25924.pdf) eFuse

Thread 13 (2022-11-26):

NebulaMiner schematic review feedback

skot, 2022-11-26:
From NebulaMiner on bitcointalk.org on 11/25/22:

Here is my Schematic review :
- I see DS4432U+ OUT0 being used for TPS40305 control, but does the OUT1 being used somewhere ? (if not use, better not creating a signal out of the package to give ambiguity...)
- where the 5V is generated ? I see +3V3 (U11), 1V8 (U5) and 0V8 (U6) being generated from 5V, and BM1397 VDD (alias of TPS40305 VOUT) being generated from VIN_M (the monitored VIN), but nowhere the 5V beoing generated...
- on the ESP, I think you inverted TX/RX, please double check it
- can you add pin header and TP for debug purpose on the 3V3 RX/TX/RST, (additionnaly to J3), and add also I2C SDA/SCL signal on this debug pin header ?
- can you use an optional (with a serial 0R resistor) signal from a CLK_OUT of the ESP (pin 13/14/34/33/32 up to you) going to the BM1397 CLKI instead of the U1 one. I may want to try later if MCU can generate this clock by SW so we have control on the hashrate of the BM1397...
- on the BM1397 you pulled down BI (with R4) are you sure it will not being used ? on BM1385 datasheet it is noted as a Busy Input (internal schmit trugger and pull down). Maybe you can link it to a GPIO of the MCU, we will see later if needed. (and add the 3V3 signal to the debug pin header too).
- for the voltage level translators (U2/U3/U4), I used to use TSX0104 in my previous design, it is easy to use because bidirectionnal. Did you consider them ?
- for EMC2101, the ALTER#/TACH pin can be configured as input (TACH monitor to mesure Fan RPM) or output (ALERT# signal to trigger an IRQ on MCU when special temp/tach conditons are met). I see more value having an ALERT# signal from it to the MCU to trigger an interrupt for Temperature Critical exceeded (with hysteresis to deassert the signal). The FAN RPM is not very usefull for us. Also EMC2101 porpose a Look-up Table of 8 stages so we can control by hardware FAN speed accoding to BM1397 internal temperature. Maybe what you can do, is link the EMC2101 ALERT#/TACH pin to a MCU GPIO, and the FAN TACH to another MCU GPIO (be careful of voltage level here), and SW will be able to configure EMC2101 in TACH reading for some seconds, by propagating the FAN signal, then switch back to ALERT interrupt for a longer period (1h ?). So most of the time we use Interrupt monitor, and only once in a while do a fAN RPM measurement for UI needs...
- it would be usedfull to have the BM1397 VDD on a ESP ADC input to measure the BM voltage
- it would be usefull to have the TPS40305 PGOOD linked to a ESP GPIO to know if Power is Good

skot, 2022-11-26:
@skot comments;

Here is my Schematic review :
- I see DS4432U+ OUT0 being used for TPS40305 control, but does the OUT1 being used somewhere ? (if not use, better not creating a signal out of the package to give ambiguity...)

The DS4432 is a dual channel part. We only need one channel. I didn't see a cheaper/better stocked current DAC alternative. The DS4432 datasheet doesn't have much to say about unused outputs. my guess is that you leave the unused channel floating and make sure not to enable it in software. (They default to off on startup)

- where the 5V is generated ? I see +3V3 (U11), 1V8 (U5) and 0V8 (U6) being generated from 5V, and BM1397 VDD (alias of TPS40305 VOUT) being generated from VIN_M (the monitored VIN), but nowhere the 5V beoing generated...

The input to the bitaxeMax is 5V. that happens at J1 and J2. There isn't any protection happening yet. Maybe that's a good idea? Any suggestions on how you would do that? I created a github issue for this. https://github.com/skot/bitaxe/issues/12

- on the ESP, I think you inverted TX/RX, please double check it

wow, oops! nice catch.

- can you add pin header and TP for debug purpose on the 3V3 RX/TX/RST, (additionnaly to J3), and add also I2C SDA/SCL signal on this debug pin header ?

sure

- can you use an optional (with a serial 0R resistor) signal from a CLK_OUT of the ESP (pin 13/14/34/33/32 up to you) going to the BM1397 CLKI instead of the U1 one. I may want to try later if MCU can generate this clock by SW so we have control on the hashrate of the BM1397...

The BM1397 has a decent PLL hashrate clock that is configurable through a couple registers. I think this is the traditional way to change the hashrate (with the corresponding core voltage change). But I agree it would be interesting to play around with this.. I'll add it.

- on the BM1397 you pulled down BI (with R4) are you sure it will not being used ? on BM1385 datasheet it is noted as a Busy Input (internal schmit trugger and pull down). Maybe you can link it to a GPIO of the MCU, we will see later if needed. (and add the 3V3 signal to the debug pin header too).

I'm pretty sure it's not needed, at least on a single ASIC chain. But if we switch to the TSX0104 level shifter, there is a spare channel, so I can hook this up.

- for the voltage level translators (U2/U3/U4), I used to use TSX0104 in my previous design, it is easy to use because bidirectionnal. Did you consider them ?

I initially avoided it because I remember it being kinda slow. But now that I'm looking at the datasheet I see that's for open-drain mode (like for I2C). In push-pull mode it's 24Mbps, which should be fine for us. I see it's in stock too -- I'll switch to it. thanks for the reccomendation

- for EMC2101, the ALTER#/TACH pin can be configured as input (TACH monitor to mesure Fan RPM) or output (ALERT# signal to trigger an IRQ on MCU when special temp/tach conditons are met). I see more value having an ALERT# signal from it to the MCU to trigger an interrupt for Temperature Critical exceeded (with hysteresis to deassert the signal). The FAN RPM is not very usefull for us. Also EMC2101 porpose a Look-up Table of 8 stages so we can control by hardware FAN speed accoding to BM1397 internal temperature. Maybe what you can do, is link the EMC2101 ALERT#/TACH pin to a MCU GPIO, and the FAN TACH to another MCU GPIO (be careful of voltage level here), and SW will be able to configure EMC2101 in TACH reading for some seconds, by propagating the FAN signal, then switch back to ALERT interrupt for a longer period (1h ?). So most of the time we use Interrupt monitor, and only once in a while do a fAN RPM measurement for UI needs...

I feel like knowing the fan RPM is important, at the very least for feedback -- is the fan going the speed we set? And for doing a sanity check on the fan -- is it connected and working? I see what you are saying about the ALERT function though. I'll hook it up to a MCU GPIO with a voltage divider.

- it would be usedfull to have the BM1397 VDD on a ESP ADC input to measure the BM voltage

good idea, i'll add that

- it would be usefull to have the TPS40305 PGOOD linked to a ESP GPIO to know if Power is Good

good idea, i'll add that

skot, 2022-11-26:
most of these have been addressed in 1a5a904 and 8d23cc9

rapsacw, 2022-12-07:
You are working on a similar idea as I am, looking around your project motivated me to publish my work so far, maybe you can find something useful? https://github.com/rapsacw/AsiNine-Pyramid

Closed 2023-10-11.

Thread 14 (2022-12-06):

Need manufacturing files (Gerbers, Drill files, Centroid, etc) for ordering PCBs

WillR06, 2022-12-06:
I'm trying to print of the board through jlcpcb and they're saying there is no. drill layer for the board?

skot, 2022-12-06:
It's possible I forgot to generate the drill file -- which branch are you using?

WillR06, 2022-12-06:
Master branch

WillR06, 2022-12-06:
Also would it be possible for you to add just the gerber files somewhere so it's a simple process to get the boards printed on somewhere like jlcpcb?

skot, 2022-12-06:
> Also do you have any alternatives i can use instead of the "2388-PCT330/10DM-ND" capacitors? they're 330uF 10v 20% and they're out of stock on digi key but they cost £50 just to ship 10 which is a bit much for a small amount of them?

Can you make a new issue for this? I'll try and come up with some replacement ideas

robomaniac, 2022-12-06:
> > Also would it be possible for you to add just the gerber files somewhere so it's a simple process to get the boards printed on somewhere like jlcpcb?
>
> I've been thinking about this a bit; I think it's probably best not to distribute the manufacturing files (gerbers, drill files, centroid, etc), especially for a very early stage project like this. It's kinda like distributing the binaries on a SW project. There are so many different PCB/A vendors with different requirements, that it's probably best to generate them yourself. Luckily, it's really easy with KiCad. I'll put together a short how to and add it to this repo.

I sort of disagree with that statement. If your design use standard holes and process it should be good to be manufacturer by different fab house. If you make very small trace and holes that certain fab house can only do then yes you are right.
I would suggest you post gerbers and the place your ordered from.  I don't use kicad so I can't generate gerbers. I would rather upload gerbers and quickly test this PCB before I decide to make my own PCB with my needs.

skot, 2022-12-06:
> I sort of disagree with that statement. If your design use standard holes and process it should be good to be manufacturer by different fab house. If you make very small trace and holes that certain fab house can only do then yes you are right. I would suggest you post gerbers and the place your ordered from. I don't use kicad so I can't generate gerbers. I would rather upload gerbers and quickly test this PCB before I decide to make my own PCB with my needs.

I'm willing to revisit this when the design settles a bit. Right now, in the early stages, you should definitely open up the project and understand what you're getting yourself into before ordering PCBs.

I highly recommend checking out KiCad. It's gotten significantly better since version 6. It's also free, installs easy, and works on Mac, Linux and PC. The OSHW world has pretty much all moved over to KiCad from Eagle.

Closed 2023-01-27.

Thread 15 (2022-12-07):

Need some alternatives for parts

WillR06, 2022-12-07:
In need of some alternatives for the part listed as "2388-PCT330/10DM-ND" as they're out of stock on Digi key and will take almost 2 months with £50 shipping for only 10. Is there any capacitors that I can order instead that will work without needing to adjust the pcbs?

WillR06, 2022-12-08:
would. "TAJE337M010RNJ" on arrow work as a substitute?

WillR06, 2022-12-08:
its 1ohm instead of 0.9 ohm which is the only difference

skot, 2022-12-19:
Hey, sorry for the late response. `TAJE337M010RNJ` should work fine!

10V rating is probably overkill too. I bet the cheaper, 6.3V `TAJD337K006RNJ` would also work.

robomaniac, 2022-12-20:
I suggest you read about "capacitor derating". I believe the same effect is found on tantalum capacitor. Murata does have great tool (SimSurfing) to see the effect of derating or DC bias.

in nutshell the capacity of the capacitor rapidly declines as the DC voltage rises. So if you apply 5V on the 6.3V you won't get 330uF but sometimes half that value! So going to 10V and more is good idea.

in your case this is decoupling but some case it's a filter thus have greater impact of on design.

WillR06, 2022-12-21:
I was wondering if "TAJD337M010RNJ" would also work, sure its more expensive but its pretty much the exact same part but works out cheaper than the original part

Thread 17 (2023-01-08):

JTAG connector problem for ESP32-S3-WROOM-1

barnix2001, 2023-01-08:
Hi! Bitaxe is a great project. Something is wrong about JTAG for ESP32-S3-WROOM-1.
Your JTAG on PCB is: GPIO9(17), GPIO12(20), GPIO13(21), GPIO14(22), GPIO21(23), GPIO47(24)
JTAG for ESP32-S3-WROOM-1 in doc is: IO42(TMS)(35),IO41(TDI)(34),IO40(TDO)(33),IO39(TCK)(32)
[See Image](https://i.ibb.co/jfnyXDq/periph3.png)

barnix2001, 2023-01-08:
I do not understand the scope of this connector. Maybe if you see the Lolin S3 PRO Devkit for ESP-S3-WROOM-1 you can place a connector for TF micro SD card or a TFT display.
[See Image](https://i.ibb.co/3SBHHNx/esp32c3-1.png)

skot, 2023-01-10:
That connector is just to break out some GPIO for experimenting. I didn't have a specific plan for it.

Breaking out JTAG is a good idea though; I'll add that on the next rev!

barnix2001, 2023-01-21:
If you need braiins open souce files (bm1387.rs, axi_bm13xx_tb.sv) you can download from this link:
[https://drive.google.com/drive/folders/1gXt9nkUYpodYeJaFKOCNf2Z-g28HXuWY?usp=sharing](https://drive.google.com/drive/folders/1gXt9nkUYpodYeJaFKOCNf2Z-g28HXuWY?usp=sharing)

skot, 2023-01-21:
Ooo, yes I would like those files. @barnix2001 the directory you posted is empty for me

barnix2001, 2023-01-21:
Send me your e-amil address from google and I will send the link from google drive.
My email is: barnix2001@gmail.com

barnix2001, 2023-01-21:
Try this link: [https://uploadnow.io/f/7LsPxM3](https://uploadnow.io/f/7LsPxM3)

skot, 2023-01-21:
got it, thanks!!

skot, 2023-01-27:
I'm going to close this issue for now. If anyone stumbles upon this issue looking for the braiins open source files, check this; https://github.com/skot/braiins

Closed 2023-01-27.

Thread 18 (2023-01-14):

I2C SDA cannot be on GPIO46

skot, 2023-01-14:
According to the Espressif [Boot Mode Selection ](https://docs.espressif.com/projects/esptool/en/latest/esp32s3/advanced-topics/boot-mode-selection.html) doc, GPIO46 being pulled high breaks the serial bootloader.

> GPIO46 must also be either left unconnected/floating, or driven Low, in order to enter the serial bootloader.
> In normal boot mode (GPIO0 high), GPIO46 is ignored.

Pick another pin for SDA. All GPIO pins can be used for I2C on the ESP32-S3

skot, 2023-01-14:
The solution for these boards is to cut on the green line and then airwire from R19 over to pin 15 on the ESP32 (pink line)
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

Just need to remember that SDA on the debug header won't work anymore.

skot, 2023-01-16:
Using GPIO3 for SDA is not the best idea either. according to the [ESP32 HW Design Guide](https://www.espressif.com/sites/default/files/documentation/esp32-s3_hardware_design_guidelines_en.pdf), GPIO3 is also a strapping pin that controls the JTAG source. I need to investigate how GPIO3 strapping should be used in this case.

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

skot, 2023-01-16:
Actually... The ESP32 has configurable internal pull-ups that can be used for the I2C pins. I _think_ this means we don't need the external I2C pull-up resistors R18 and R19 at all. This means pin-16/GPIO46 can be used for SDA after all.

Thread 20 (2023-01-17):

TPS40305 feedback resistors are not right

skot, 2023-01-17:
The TPS40305 voltage regulator feedback resistors R14 and R15 are not the right values.

The good news is that this makes the TPS40305 output like 0.64V which is harmless. But you'll never be able to to adjust it up to the 1.5V it needs to be.

I'll add the correct values here soon.

skot, 2023-01-17:
For a default TPS40305 output of 1.5V the feedback resistor values should be;
R14 = 4.99kΩ
R15 = 3.32kΩ

I don't have any 4.99k resistors to try yet, so I used 4.75k for R14 and got an output of 1.452V -- not bad!

developeralgo8888, 2023-01-23:
i will have to rectify this on my prototype boards before i can continue with tests

skot, 2023-05-23:
this was fixed in 1881967

Closed 2023-05-23.

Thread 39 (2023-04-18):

Error loading symbol library BM1397

itsgudenuf, 2023-04-18:
I'm working on the socket mount to convert this into a chip tester (ItsAllGoodMining & Repair)

When I open the Symbol Editor in Kicad I get the following error

Errors loading symbols:
Error loading symbol library BM1397

Library file
'\Users\skot\Work\Bitcoin\BM1397\cad\BM1397.kicad_sym' not found

I searched the files in the repo, seems this one is missing.

Thanks

itsgudenuf, 2023-05-19:
Nevermind, it was a user error

Closed 2023-05-19.

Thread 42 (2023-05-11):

TXB0104 does not like the 1K NRSTI pulldown R1

skot, 2023-05-11:
The [TXB0104 datasheet](https://www.ti.com/lit/ds/symlink/txb0104.pdf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) says;
> If pullup or pulldown resistors are connected externally to the data I/Os, their values must be kept higher than 50 kΩ to ensure that they do not contend with the output drivers of the TXB0104 device.

This 1K pulldown causes all sorts of oscillations. Probably related to issue #35
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

skot, 2023-05-11:
The workaround for now is just to remove R1

rapsacw, 2023-05-20:
Always place all pull-downs/ups on the input side of the TXB0104, and if possible connect OE to VccA so all input states are always replicated on the output side. Pull-ups/downs are only needed for signals that are in high impedance state (during startup), and are mostly signals from your controller that are not yet configured (and maybe 1 or two from the asic).

skot, 2023-05-23:
the TXB0104 is bi-directional, so it doesn't technically have an "input side". does that matter?

rapsacw, 2023-05-23:
Heh, I doubt you use it bi-directionally (in the true sense as in switching the directionality as needed).
Anyway, place the resistors on the side that has the origin of the signal.
A little off-topic, how are things going? My project is moving slowly because I can't make up my mind on how fast the miner should be. I'm trying to stick to the max. 10-15W power consumption but I'm tempted to also make a 1THs+ version. On the software side; my esp-miner is running stable (bm1387 & bm1397) but lacks in the UI department. I think I'm going to stick with the temporary solution I've hacked up that uses a command prompt interface with some simple commands to write/type/copy/delete config files and a few shortcuts to manipulate voltage & frequency while running, all based on the WebserialLite library. I'll update the repository when I'm finished implementing the configs for pool and wifi settings.
On the BM1397 side of things; VDDIO1.8 & VDDPLL0.8 together consume only 20mA. This means a simple resistor divider can create the 0.8V for the PLL (tested and proved working using 22 & 20 ohm resistors), and it is possible (and simplest/cheapest) to use something like the mcp16251 boost converter for all asics as it can run on input voltages of below 1V (so less than Vcore) and can output 1.8V.

Closed 2023-10-11.

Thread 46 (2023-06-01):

Barrel to wire screw terminal adapter is no good for powering the bitaxe

skot, 2023-06-01:
Some power supplies come with these 2.5mm barrel to wire screw terminal adapters:
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

Unfortunately they are too high resistance for use in powering the bitaxe. They will drop the input voltage too much and/or get super hot. It's best to wire it directly.

BastelPichi, 2023-06-12:
USB c requires extra Chip to get proper Power. Also, at 5v, USB c can "only" handle 5a (Most chargers dont do). USB c Gear is quite expensive currently so I wouldnt so that.

Im actually quite Happy with spade connectors, as you can and should Just get an proper Power supply already.

Abstract Idea: use ATX Power supply connectors...

DocBrown101, 2023-10-11:
The only alternative I can see here is an XT30 or XT60 connection.

Closed 2023-10-11.

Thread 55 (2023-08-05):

ESP32-C6

Lysnyt, 2023-08-05:
Hello Skot, would be not better to use the C6 version of ESP32 instead od dual core S3.
C6 have Wifi 6 implemeted. Which is not faster but should be more reliable if there are many bitaxes connected at once.

C6:
High performance 32-bit [RISC-V](https://en.wikipedia.org/wiki/RISC-V) CPU, up to 160 MHz,[[12]](https://en.wikipedia.org/wiki/ESP32#cite_note-12) implementing RV32IMAC
    Low Power 32-bit RISC-V CPU, up to 20 MHz, implementing RV32IMAC
    512 KiB SRAM and 320 KiB ROM
    [IEEE 802.11ax](https://en.wikipedia.org/wiki/IEEE_802.11ax) (Wi-Fi 6) on 2.4 GHz, supporting 20 MHz bandwidth in 11ax mode, 20 or 40 MHz bandwidth in 11b/g/n mode
    [IEEE 802.15.4](https://en.wikipedia.org/wiki/IEEE_802.15.4) ([Thread](https://en.wikipedia.org/wiki/Thread_(network_protocol)) + [Zigbee](https://en.wikipedia.org/wiki/Zigbee))
    Bluetooth 5 (LE)
    30 (QFN40) / 22 (QFN32) programmable GPIOs

S3:
Dual-core Xtensa LX7 CPU, up to 240 MHz,[[10]](https://en.wikipedia.org/wiki/ESP32#cite_note-10) and supporting [single-precision](https://en.wikipedia.org/wiki/Single-precision) [FPU](https://en.wikipedia.org/wiki/Floating-point_unit)
        Added instructions to accelerate machine learning applications
    512 KiB SRAM, 384 KiB ROM, and 16 KiB RTC SRAM
    Capable of connecting to external [PSRAM](https://en.wikipedia.org/wiki/PSRAM) and [Flash](https://en.wikipedia.org/wiki/Flash_Memory) via [Quad SPI](https://en.wikipedia.org/wiki/Quad_SPI) or [Octal SPI](https://en.wikipedia.org/wiki/Serial_Peripheral_Interface), and share the same 32 MiB [address space](https://en.wikipedia.org/wiki/Address_space)
    Ultra-low power [RISC-V](https://en.wikipedia.org/wiki/RISC-V) (RV32IMC) coprocessor clocked at 17.5 MHz approximately
    Ultra-low power [FSM](https://en.wikipedia.org/wiki/Finite_State_Machine) coprocessor similar to previous ESP32 and [ESP32-S2](https://en.wikipedia.org/wiki/ESP32-S2)
    WiFi 2.4 GHz (IEEE 802.11 b/g/n)[[11]](https://en.wikipedia.org/wiki/ESP32#cite_note-11)
    Bluetooth 5 (LE)
    44 programmable GPIOs
    2 × 12-bit SAR ADCs, up to 20 channels
    [USB OTG](https://en.wikipedia.org/wiki/USB_On-The-Go)

skot, 2023-08-05:
Yes, definitely! I would like to switch ASAP.

Is there a similar C6 module?

Lysnyt, 2023-08-05:
In your BOM list is ESP32-S3-WROOM-1-N16R8 (which has 16 MB (Quad SPI) 8 MB (Octal SPI))
Right now ESP32-C6-WROOM-1-N4  (4 MB (Quad SPI)) available on mouser, digikey, aliexpress :)
I don´t know if the pins are compatible ...

skot, 2023-11-20:
The C6 only has a single core and it's a slower clock speed. I think we're going to stick with the S3 for now. I'll keep an eye out for a suitable RISC-V replacement in the future.  ✊

Lysnyt, 2023-11-20:
Hi Skot, is really necessary so much power for a serving module ? I mean, the calculation are done with The BM chip, not by ESP, am i wrong ?

ESP Announced :
ESP32-C5

    Single-core 32-bit [RISC-V](https://en.wikipedia.org/wiki/RISC-V) CPU, up to 240 MHz[[14]](https://en.wikipedia.org/wiki/ESP32#cite_note-14)
    400 KiB SRAM and 384 KiB ROM
    [IEEE 802.11ax](https://en.wikipedia.org/wiki/IEEE_802.11ax) (Wi-Fi 6) on 2.4 and 5 GHz, supporting 20 MHz bandwidth in 11ax mode, 20 or 40 MHz bandwidth in 11b/g/n mode
    Bluetooth 5 (LE)
    > 20 programmable GPIOs

Lysnyt, 2023-11-20:
Oh, i see. Thanks for explanation :)
Even without that your skilled programmers can use the S3 ESP-WIFI-MESH networking feature (or even Bluetooth mesh) to make one Bitaxe as master and other near as slave.
-Maybe- it could harness more computing potential such inter-connected Bitaxes for splitting jobs (MESH, Webpage, network throughput, Mining admin)

eft37, 2023-11-20:
Esp32 P4 is an upcoming faster risc-v dual core board announced 9 months ago. Maybe that one?

benjamin-wilson, 2023-11-20:
At first glance looks like it could be a substitute

benjamin-wilson, 2023-11-20:
Nevermind - no wifi

benjamin-wilson, 2023-11-20:
Although it looks like they intended for you to add a  ESP32-C2 for radio hmmmm

skot, 2023-11-20:
Ooo the P4 could be good for SeedSigner

Lysnyt, 2023-11-20:
https://en.wikipedia.org/wiki/ESP32

eft37, 2023-11-21:
> Ooo the P4 could be good for SeedSigner

I learned about Seedsigner.com via this post, you think it could do that vs a raspberry pi zero?

Closed 2023-11-20.

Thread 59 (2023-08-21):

ASIC chip temp not working

skot, 2023-08-21:
The pins I thought were the on-die chip temp sensor don't seem to be working. the EMC2101 will read 127ºC, the max temp all the time.

It's probably best to DNP resistors R7 and R8 to disconnect the EMC2101 from the BM1366 for now. (it will read 0ºC after that)

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

SatoshyBoy, 2023-09-01:
Hi Skot.

My sensor is reading the temperature. I added a pretty good thermal pad on the chip and finally got a temperature below the maximum. It is reading temperature around 63C.

Another detail that I noticed. After adding the thermal pad, the current decreases by 1A for the same hash/rate. I didn't expect that.

skot, 2023-09-01:
> My EMC2101 is reading the temperature.

Is this on the bitaxeUltra with the BM1366?

SatoshyBoy, 2023-09-02:
Sorry, It is the BM1397. I didn't notice that this topic is for the ULTRA. But BM1397 also has an issue with the temperature. I was reading 127 every time.

But there is something weird with BM1397, too. I can change the measured temperature by only changing the Vin. Usually, the bitaxe uses 5V, but if you try other voltage inputs, it has an effect on the temperature. It doesn't make sense because the VDD is always the same 1.4v, and power consumption (P=Vin*I) is constant.

Moreover, the output has a square form, which also doesn't make sense. (Yellow: temp_P. Purple: temp_N. White: temp_P - temp_N)
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

skot, 2023-09-02:
When you get that square wave on the ASIC die temp pins, is it also connected to the EMC2101?

Those die temp pins are connected to a diode (or transistor) on the die. To measure the temperature you put two different currents through it and the difference in forward voltage is proportional to the temperature. That would be one explanation for the square wave.

It also seems like you have a soldering problem and/or the ASIC is damaged. I have been able to read the chip temp just fine on several BM1397.

SatoshyBoy, 2023-09-03:
The EMC2101 is connected. I didn't know it has an active connection for parasitic resistance in series.

skot, 2023-11-20:
Confirmed the BM1366 does not have internal temp diode pins :(

Closed 2023-11-20.

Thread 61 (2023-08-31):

Add a PCB air temp sensor.

skot, 2023-08-31:
Because of #59 we're going to need a new way too measure (or approximate) chip temperature. This probably means adding a PCB air temp sensor as close to the ASIC and heatsink as possible.

a digital I2C temp sensor with the TMP75 is the most straight forward, but if there is a significant cost difference an analog temp sensor could work. We have plenty of ESP32 analog pins available.

skot, 2023-11-20:
the BM1366 has no internal temp sensor. @benjamin-wilson moved the EMC2101 up nice and close to the ASIC and I think that's working pretty well.

Closed 2023-11-20.

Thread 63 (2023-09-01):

Replace 1.8V LDO U5 with 1.2V MCP1824T-1202E

benjamin-wilson, 2023-09-01:
voltages XP hashboard are 0.8V and 1.2V, not 0.8V and 1.8V like on the ultra

bart, 2023-09-02:
S19a Pro for example also is 1.8V

benjamin-wilson, 2023-09-02:
```
developeralgo222 — Today at 10:26 AM
Tested today. if you are using the original ultra dev board without any changes we have now tested  that if  U5 @ 1.8V LDO  <===> J-Connector (1V8)  <==>  UART  Serial ( Input 1.8V or 1.2V  both work and able to communicate to the BM1366 AG/AL chip )
But if you have it same way as in S19 XP Hashboards where its supposed to be 1.2V it does NOT work in current Ultra Dev board i.e  if  U5 @ 1.2V LDO  <===> J-Connector (1V8)  <==>  UART  Serial ( Input  1.2V  Does NOT work and will not communicate to the BM1366 AG/AL chip )
For those who planned to switch U5 to 1.2V please hold off until we can figure out why it does not work with 1.2V LDO @ U5
```
Hold off for now

skot, 2023-11-20:
the minimum supply voltage for the crystal oscillator we are using is 1.8V. if we switch to 1.2V we need to sort this out.

AxisRay, 2024-01-27:
1.2v LDO:  TLV70212QBVRQ1
1.2v crystal oscillator: SX3M25.000E20F30THN
Test OK

DirceuPY5DK, 2024-02-18:
and if at the input of pin 14 you place a voltage divider with two resistors in series, 1k and 2k to ground, the result will be 1.2v at the input of the BM1366... the other line would have a voltage of 1.8v and at pin 14 would have 1.2v. It's just an idea.

benjamin-wilson, 2024-04-19:
Tested with a 1.2V LDO and 1.2v oscillator, it did not work.
https://www.digikey.com/en/products/detail/onsemi/NCP114ASN120T1G/6560601
https://www.lcsc.com/product-detail/Oscillators_Shenzhen-SCTF-Elec-SX3M25-000E20F30THN_C5137262.html

AxisRay, 2024-04-21:
> Tested with a 1.2V LDO and 1.2v oscillator, it did not work. https://www.digikey.com/en/products/detail/onsemi/NCP114ASN120T1G/6560601 https://www.lcsc.com/product-detail/Oscillators_Shenzhen-SCTF-Elec-SX3M25-000E20F30THN_C5137262.html

I have built several bitaxes with 1.2V LDO and oscillator, and all of them works well.
Is it the oscillator or the ASIC that is not working correctly?
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

skot, 2024-04-25:
I'll try this out with some LCSC drop-in 1.2V oscillators. if it works I'd like to include in 402

skot, 2024-04-26:
Switched my v400 to the `MCP1824T-1202E` 1.2V LDO and `C5137262` 1.2V 25MHz Oscillator. seems to be working -- I'll keep an eye on it.

skot, 2024-06-07:
officially changed in 402

Closed 2024-06-07.

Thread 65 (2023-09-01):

Replace power connection with 2.1ID 5.5OD barrel connector

benjamin-wilson, 2023-09-01:
Most 5v power supplies available come with a 2.1ID 5.5OD barrel connector. This will reduce the amount of work to get a bitaxe working and provide a little protection against shorting.

When creating the connector large pads should be also made underneath if possible so that the connector can be de-soldered and wires can be soldered directly to the PCB for other projects.

benjamin-wilson, 2023-09-01:
Cost effective candidate:  https://www.digikey.com/en/products/detail/tensility-international-corp/54-00127/9685436

skot, 2023-10-11:
this is fixed in v1.1

Closed 2023-10-11.

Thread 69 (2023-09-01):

make the heatsink clip holes a bit smaller.

skot, 2023-09-01:
@benjamin-wilson says they are too loose.

skot, 2023-09-01:
> An M3 dowel is 3.003-3.008mm
So a 3mm hole would have a nice interference fit and be compatable with the fan

Closed 2023-11-10.

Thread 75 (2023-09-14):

Fan and heatsink specification

smartm0use, 2023-09-14:
Can you add these info to README file?

skot, 2023-09-14:
it's already there: https://github.com/skot/bitaxe#hardware

smartm0use, 2023-09-15:
There I can read that I can buy a "[40x40mm heatsink and 5V fan](https://www.aliexpress.com/item/2251832861666365.html)":

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

Then, I read "Noctua NF-A4x10 5V 4-Pin fan".

So, I deduce that I can buy a 4-Pin fan... but there is not 4-Pin fan in the Aliexpress link.

What's wrong? The link or the 4-Pin information?

smartm0use, 2023-09-17:
In addition, I see that it is possible to get a fan from a random seller on Aliexpress, otherwise get a Noctua fan. I saw that Aliexpress fans has more or less the same characteristics, especially in terms of rpm and db, but costs 1/3 or even 1/4.
I was wondering if I opt for a cheap fan and then maybe it spins more slowly, stops or has problems cooling, in short, if it doesn't manage to cool properly, what happens?
Does the ASIC chip burn out or does some sensor come into play so bitaxe is saved?

skot, 2023-10-11:
we are working on some firmware to shut down the ASIC and/or power in an over-temp situation. Currently there is no protection.

This is going to be a firmware fix, so I'll close this issue.

smartm0use, 2023-10-11:
Ok, I see. Thank you for the information.
What about the other questions?
Is that Aliexpress link misleading?

skot, 2023-10-11:
the bitaxe is compatible with 5V fans, either 2-pin, 3-pin or 4-pin.

Closed 2023-10-11.

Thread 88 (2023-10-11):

Fix U9 footprint

benjamin-wilson, 2023-10-11:
I just got reminded that U9's footprint may be wrong. Needs investigation against the data sheet.

skot, 2023-10-11:
the little tabs coming off the GND pad were spaced too far apart. fixed in f07d92f

shufps, 2023-10-22:
You designed the footprint by yourself?

What is wrong using `Package_SON:VSON-10-1EP_3x3mm_P0.5mm_EP1.65x2.4mm_ThermalVias` ?

shufps, 2023-10-23:
Kicad has this footprint in the library:

`Package_SON:VSON-10-1EP_3x3mm_P0.5mm_EP1.65x2.4mm_ThermalVias`

skot, 2023-10-23:
wow, I didn't think to look in the KiCad library for that goofy footprint. It's pretty close, but not exactly what the TI datasheet calls out..

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

shufps, 2023-10-24:
Hmm idk if it matters much. Datasheet says `VSON (10) 3x3mm` and normally I just rely on this and use what Kicad gives me :man_shrugging: :grimacing:

skot, 2023-10-24:
lemme know how it goes! the TPS40305 footprint has been a major source of soldering troubles for bitaxe assemblers.

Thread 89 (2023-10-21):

Mode Pins on BM1366

shufps, 2023-10-21:
Hi,

I'm a bit confused about how the caps C4 and C16 are connected to the BM1366.

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

What purpose do the `mode_0`, `mode_1` and `modeo` pins have?

And what I also wondered - where did you find this awesome information?

I searched a lot and didn't find any schematics to the BM1366 - not even in the repair guides of Bitmain.

Thx,
Thomas

skot, 2023-10-21:
The mode pins change the direction of the data pins. Ie mode1 is inputs on the left and outputs on the right. Mode0 is the opposite.

Those mode names are arbitrary of course because we don't have any schematics or pinouts.

shufps, 2023-10-21:
Thank you, this is almost what I thought for what they are :sweat_smile:

What I still don't understand is that `mode_1` and `modeo` have caps to `0.8V`.

So I suspected there must be more going on - like extra caps for a charge-pump that uses the pins that are labeld with `modeo` and `mode_1` or so idk.

If it's not a charge pump then I absolutely have no idea what purpose the caps have :sweat_smile:

shufps, 2023-10-21:
perhaps you already saw - I did a fork for a Raspberry Pi HAT and I removed everything I thought I wouldn't need :see_no_evil:

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

I also removed the two caps because I couldn't explain for what they are but at the same time I'm suspicious that I made a mistake by removing them :see_no_evil:

shufps, 2023-10-22:
I revised the schematic on my fork and added back the 1µ caps. Probably it was stupid to remove them in the first place anyways :grimacing: You seem to have real hardware for reverse engineering - I ofc don't and it was stupid to assume to know better :see_no_evil:

Ordered my HAT and parts ... let's see how it's going :crossed_fingers:

skot, 2023-10-23:
Now you have me wondering about this too. What we have is definitely working on the single-ASIC bitaxe. I'm going to look a little deeper into this for the multi-ASIC bitaxeHex.

I don't think it's a charge pump. From what I can tell it's just trying to passthrough the mode from one chip to the next in the chain.

Closed 2023-10-23.

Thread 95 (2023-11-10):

TPS40305 PGOOD signal is incorrectly pulled up to BP

skot, 2023-11-10:
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

according to the [TPS40305 datasheet](https://www.ti.com/lit/ds/symlink/tps40305.pdf?ts=1699556087481) BP is a 6.5V Output bypass for the internal regulator. We don't want to pullup the PGOOD open-drain signal to that as it connects to the ESP32.

the easy fix here is to just remove R11

benjamin-wilson, 2023-11-10:
Were there any consequences to having R11 populated in the past? R11 should be removed from all versions?

skot, 2023-11-10:
it doesn't _seem_ like it's been causing any problems, but pulling up to 6.5V is going to be out of spec for the ESP32. we should test this, and if it's good, then yes remove it from all versions.

skot, 2023-11-10:
I pulled off R11 on a Ultra 202 and it seems to be working fine.

skot, 2023-11-20:
fixed in 22f5b3f

Closed 2023-11-20.

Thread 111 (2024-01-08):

Wrong Noctua Fan Link in readme.md

satoshiisland-org, 2024-01-08:
In  the readme.md is the 12V Fan linked: https://noctua.at/en/products/fan/nf-a4x10-pwm

I guess it should be the 5V version here: https://noctua.at/en/nf-a4x10-5v-pwm

Just a small detail.

skot, 2024-01-08:
good catch, thank you!!

Closed 2024-01-08.

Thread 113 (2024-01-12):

Button footprint too small

derhaegr, 2024-01-12:
Including pads it should be at least 5mm
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

skot, 2024-01-12:
Wow, yes you are right. it's not right. from the [datasheet](https://www.citrelay.com/Catalog%20Pages/SwitchCatalog/CS1213.pdf);
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

this means the pads should be 1.8x0.9mm and the pad center 2.05mm from the part center.

skot, 2024-01-12:
correct size on the right;
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
I think I just grabbed a footprint from Ultralibrarian without checking it 😣

skot, 2024-01-12:
@derhaegr I just pushed a fix. can you double check it?

derhaegr, 2024-01-12:
@skot Board file seems ok but the gerber has 0.88mm pads or is it just me?

Closed 2024-01-12.

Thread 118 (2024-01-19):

Bitaxe 1366 Severely Underhashing

555-FILK, 2024-01-19:
Hello,

I like playing around with desktop miners so I got my hands on a Bitaxe 1366 after hearing about it on various podcasts and reading about it online. I thought it would be a nice complement to my NerdMiner.

I received the 1366 and have been running it for about a week now and it has been underhashing since day one. I believe it should hash up to 550 GH/s but I am consistently getting only about 250 H/s, yes hash per second, not even KH/s.

Any tips for improving performance? Not that I expect to find a block, but if I am running it I might as well get it to high performance.

Thank you,
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

benjamin-wilson, 2024-01-19:
Hi, where did you get your bitaxe from? It looks like it went into overheat protection mode at some point. If you go into the settings page simply reset the frequency and voltage to the defaults.

555-FILK, 2024-01-19:
Thank you for the quick reply! I got it from D-Central. I went into settings and the Frequency was blank and the Core Voltage was blank, so I set them to their defaults, 485 and 1,200, respectively. Unit is now restarting. I will update here if it worked. Thanks again.

555-FILK, 2024-01-19:
10 minutes in and there is an obvious difference, that seems to have been the issue. However, now there is a warning about low voltage, see attached. Do I need to adjust anything in settings? Should I care? Thanks again.
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

benjamin-wilson, 2024-01-19:
Your chip temperature is very hot, is the fan going? What fan? Is there thermal paste?

555-FILK, 2024-01-19:
Yes the fan is going. It is set to "Invert Fan Polarity", "Automatic Fan Control" is off, and Fan Speed is 100% "S19 Simulator." The fan is the stock fan installed by D-Central, and I cannot confirm whether D-Central installed thermal paste. Attached are some photographs.
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

benjamin-wilson, 2024-01-19:
Can you take a picture of the back of the PCB?

555-FILK, 2024-01-19:
Here is the front and back.
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

benjamin-wilson, 2024-01-19:
Is it just the picture or is there some bridging on U8 and U10 between the pins?

555-FILK, 2024-01-19:
Here is a larger picture of U8 and U10. I don't see any explicit bridging but I did not look through any loops. I think it may just be the picture. I can look at it through loops if you'd like.
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

benjamin-wilson, 2024-01-19:
Yes, please ensure there isn't any bridging.

555-FILK, 2024-01-20:
I think you may have figured it out. After changing the Frequency and Core Voltage to defaults, it ran fine for about 2 hours, but as you noticed, it was getting very hot. After about 2 hours, it went back into overheat protection mode, the Frequency and Core Voltage values are now blank and it's back to hashing at about 200 H/s. So maybe there is bridging. I will reach out to D-Central, maybe I got a lemon. Thank you.
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

kakawlala, 2024-01-20:
For the Bitaxe Ultra setting, I recommend using a 40x40x20mm fan, which has greater air pressure to reduce heat.  I purchased my device from Bitcoin Merch and the fans they shipped were 20mm thick and I had to reapply thermal paste.  And updated to version 2.0.6 by itself. This version corrects the low voltage warning.  Under the preset frequency and voltage, the temperature is below 60 degrees Celsius.  I increased the frequency to a maximum of 575Hz and a maximum voltage of 1300mV.  The highest temperature will be below 65 degrees Celsius.  (If the temperature cannot be suppressed below 68 degrees Celsius, the device will easily trigger the low H/S protection) The fan will run at 4700~4900RPM during overclocking, so I replaced it with an NF-A4x20 5V PWM fan to reduce noise.  I have tried the 10mm thick fan, 10mm which should be more suitable for working on the early Bitaxe 1397.

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

monster4866, 2024-01-22:
i have the solution: The power supply is crap, buy a better one, you need at least 5000mv input voltage, then the fan is quiet, but take the one from D-Central, it has a higher speed and cools better, I also have a separate power supply bought

https://www.amazon.de/dp/B01HRR9GY4?psc=1&ref=ppx_yo2ov_dt_b_product_details

5v and min 4A, The power supply from them is cheap Chinese junk

LG

monster4866, 2024-01-22:
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

555-FILK, 2024-01-23:
Update: I put a regular house fan in front of the unit, set the Frequency and Core Voltage to defaults, and it has been running for 5+ hours and it has been running at 350 GH/s to 550 GH/s.
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
This is the longest I've gotten it to run at that GH/s rate. The moment I turn off the house fan off, the temperature begins rising. I'm not going to keep this setup long term, it's just a test, which confirms in my mind the stock fan is insufficient, right? [kakawlala](https://github.com/kakawlala) recommended I upgrade to a 20mm fan, would that resolve this issue?

As for the low voltage, I am still getting that issue. [kakawlala](https://github.com/kakawlala) mentioned updating the firmware. But, [monster4866](https://github.com/monster4866) recommended replacing the power supply. Any comments or recommendations on this issue?

benjamin-wilson, 2024-01-23:
I recommend you return and replace your unit, it's not operating how it should.

kakawlala, 2024-01-23:
Here are the reasons why I recommend using 20mm thick fans on BITAXE ULTRA.  I purchased mine from Bitcoin Merch and they shipped it to me with a 20mm thick fan.

But the photos on their website are for 10mm thickness.  After receiving the item, I didn't notice it at first.

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

I only found that under over-frequency and over-voltage conditions, the fan can control the temperature and prevent protection from reducing H/S, but the noise is obvious.

So I followed the recommendation and used the noctua NF-A4x10 fan, which indeed reduced the noise, but it couldn't suppress the temperature.  Only then did I discover that the shopping website was equipped with a 20mm thick fan.  After that I changed again to noctua NF-A4x20 fan.

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

555-FILK, 2024-01-23:
Update: I tried another 5V/4A DC PSU and that resolved the "Danger: Low Voltage" issue. It's disappointing that D-Central charges $15 for a PSU that doesn't work.

However, the alternate PSU did not resolve the overheating issues. So far, I updated the firmware and the PSU, but the heating is still an issue. I guess the next step is to upgrade the 10mm fan to a 20mm fan. Upgrading to the 40x40x20 Noctua 4pin fan next.

I want to thank everyone for their comments, suggestions, etc. What a great community.

555-FILK, 2024-01-25:
Final (?) Update: Bitaxe has been running for 12+ hours with a hash rate of over 400 GH/s. What I did to get here, with all of your help:

1. Update firmware;
2. Replace the PSU ($10.00); and
3. Replace the stock 40x40x10 fan with a 40x40x20 fan ($15.00).

I reached out to D-Central when I first posted here, but they still have not responded. It's disappointing that they charged $15 for the PSU that was junk and I paid only $10 for a replacement PSU that works. That's too bad because they had quick shipping and handling, and they included some cool stickers and 3D printing trinkets in the box it came it, which was a nice touch.

Anyways, thanks everyone for your help. Happy hashing, tick tock next block.
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

kakawlala, 2024-01-25:
You can cross test.  For example, use a new fan paired with the power supply the original store gave you.  The original power supply can't reach 5V, it will be around 4.85~5V, but this should make the temperature lower.  Although there was a low voltage prompt before, the monitoring value has been revised and relaxed since V2.0.5.  The main reason for low H/S protection is that the temperature detection is too high.

Next, you can set the maximum operating frequency and voltage, which will result in higher H/S.  The temperature should be below 66 degrees Celsius.  If high temperature protection occurs and H/S is reduced, thermal paste may need to be reapplied.

In the past, my experience was that when I turned the screws to replace the fan, the slight displacement caused damage to the contact surface of the thermal paste between the heat sink and the chip, and it needed to be reapplied.  After that, I used to fix the fan on the radiator first, apply thermal paste, and finally install the entire fan and radiator on the board.

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

CaptainCodeman, 2024-02-05:
I have 2x BitAxe's, from different vendors. One runs much cooler than the other - usually around 38 C vs 60 C for the other (which was hovering around 68 C before I took the heatsink off and re-applied the thermal paste).

One had the "Danger: low voltage" warning and seems like it consumes more power (but is the cooler one) so I replaced the PSU that came with it and it now seems to be fine. This is what I used in case it helps anyone: https://www.amazon.ca/dp/B087LY41PV?psc=1&ref=ppx_yo2ov_dt_b_product_details

Power Consumption: | 13.84 W
-- | --
Input Voltage: | 4,996 mV
Input Current: | 2,736 mA
Frequency: | 575 Mhz
Core Voltage: | 1200 mV
Measured Core Voltage: | 1194 mV
Fan Speed: | 5654 RPM
Chip Temperature: | 60 C

Power Consumption: | 15.77 W
-- | --
Input Voltage: | 4,979 mV
Input Current: | 3,168 mA
Frequency: | 575 Mhz
Core Voltage: | 1200 mV
Measured Core Voltage: | 1216 mV
Fan Speed: | 6931 RPM
Chip Temperature: | 38 C

The one that runs cooler has a 10mm height fan on it, the hotter one a 20mm fan, go figure! Both just what came with them, no fancy Noctuas (yet)

skot, 2024-02-06:
> I have 2x BitAxe's, from different vendors. One runs much cooler than the other - usually around 38 C vs 60 C for the other (which was hovering around 68 C before I took the heatsink off and re-applied the thermal paste).

What HW version are each? I'm guessing the 15W / 38C unit is actually running much hotter.

CaptainCodeman, 2024-02-06:
The one reporting the hotter temp says 201, I can't see a version on the other one though.

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

I only have a cursory knowledge of electronics, but thought it was odd that the one using more power would really be cooler, esp. by that much, and it did trip into the overheat protection mode a couple of times (where the frequency and power settings blank, and the fan control is cleared)

They have both been running fine since the thermal paste & new PSU though (a couple of days).

skot, 2024-02-06:
Yeah, the one that is reporting a cooler temperature is an older revision that doesn't have the sensor as close to the ASIC. They are probably both actually running at the same temp. You can put your fingers on the side of the heatsink to compare.

skot, 2024-02-06:
That could be due to the faster fan, and/or just subtle differences in the chip bin. Glad we got this sorted out!

Closed 2024-02-06.

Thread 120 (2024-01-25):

Remove display header in favor of staggered holes

benjamin-wilson, 2024-01-25:
1. The display header pads are relatively small and may rip out when the display is removed.

2. The exposed bit of the pads are too large and need to be covered with more mask. The large pads cause the header to tilt during reflow, making the screen not parallel/perpendicular. Making them the same height as the pins should make it self-align as well.

AxisRay, 2024-01-26:
I think using an FPC socket would be better? This way, we can directly attach the screen to the PCB.

skot, 2024-01-26:
Should we fix this for 205?

I'm not really a big fan of that display connector. It seems too tall and too lose, making the display look wonky often.

I'll take a look at some options.

benjamin-wilson, 2024-01-26:
The SMD version is significantly snugger in fit - this is why i'm having issues with pads ripping

benjamin-wilson, 2024-01-26:
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
The height seems appropriate as well.
One option to completely eliminate it would be to have staggered holes and insert it directly into the PCB
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

AxisRay, 2024-01-28:
my solution
I printed a 10mm*10mm*10mm cube and stick it to the pcb.

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

benjamin-wilson, 2024-01-30:
The more I think about it - the best part is no part. The display fits really nice and secure into those staggered holes while being easy to insert/remove. The tube the header comes in is a big pain as well.

Closed 2024-01-30.

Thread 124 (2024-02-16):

Fan PWM speed control should be pulled up to 5V instead of 3.3V

skot, 2024-02-16:
From K1 in the discord;

> PWM fan control is open drain
those fans typically have internal pull-ups to 5V
the EMC23xx series controllers are 5V tolerant for open drain applications, otherwise do 3V3 push pull
the fan controller is switching ON 3V3 into a 5V circuit and then OFF to GND (sinking it low) - the sinking action is what theoretically controls the fan
some things absolutely demand a 5V driver though
if you are designing a new board, it needs to be pulled to 5V or driven push/pull to 5V with a capable complementary level FET pair or level shifter or MCU

existing circuit:
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

skot, 2024-04-05:
the BM1368 supposedly has digital, internal temp sensor. if this is true and we can use it, we might not need the EMC2101 at all.. just drive the fan from the ESP32

skot, 2024-04-07:
> EMC23xx series controllers are 5V tolerant

But what about the EMC2101 on the bitaxe. need to check this out

skot, 2024-04-25:
added in 9afeb2c

Closed 2024-06-07.

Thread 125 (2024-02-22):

Ask for help

kakawlala, 2024-02-22:
I made bitaxeUltra 204 on PCWAY. The chip used is BM1366AL. I used esptool to flash esp-miner-factory-204-v2.0.7.bin, but it didn't work and it showed that it could only accept new jobs.  How should I measure whether there is a component failure or misalignment?  Or maybe my programming method is wrong.
The heat dissipation is also normal and there is no high temperature protection.

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

The power supply used is also normal and it works on another bitaxe I purchased online.  But on the finished product produced by PCway, it is observed that the input power is only more than 300 mA, and it should be 3000mA.

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

Fortunately, two of the five devices are working normally, but I don't know how to use the TP point to determine which part of the three faulty devices is faulty.

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

skot, 2024-02-22:
Everything looks good but it's not mining sounds like an ASIC issue to me. Likely the ASIC isn't soldered properly, or the chip is bad.

skot, 2024-02-22:
I'm going to close this as it isnt a bitaxe issue. Can you bring this up on the OSMU Discord? There is an invite link at bitaxe.org

Some other people have attempted PCBWay assembly with similar results.

kakawlala, 2024-02-22:
> 一切看起來都不錯，但對我來說，這不是挖礦，聽起來像是 ASIC 問題。可能是 ASIC 焊接不正確，或是晶片損壞。

Thanks for your reply, you are right.  After reinstalling BM1366 on the 3 previously faulty devices, there is still no hash value.  Later, after I swapped the chips of a normal and abnormal device, the results were also swapped.  Sure enough, it was a fault with BM1366.

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

Closed 2024-02-22.

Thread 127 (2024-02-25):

Request: BOM file for different suppliers e.g. jlcpcb

TheMissingNTLDR, 2024-02-25:
Request: Would it be possible to add jlcpcb dot com's BOM file please.

There is a Sample Template they would expect the format to be in, on this page if that helps..
https://jlcpcb.com/help/article/45-Bill-of-Materials(BOM)-File-for-PCB-Assembly

Sorry I am new to this field, first time I am geting involved in this area, have not got a clue how to convert [existing BOM xlsx](https://github.com/skot/bitaxe/tree/master/Manufacturing%20Files) in to this supplier.

Thank you

TheMissingNTLDR, 2024-02-25:
Update: Just saw this old pull request from March 2023.
https://github.com/skot/bitaxe/pull/38
I suppose then every branch needs to be updated and reviewd for each version change? Am I correct?

TheMissingNTLDR, 2024-02-27:
> JLCPCB doesn't stock a lot of parts used on the Bitaxe. You'd need to find replacement parts that they do stock, which can be difficult as many of the datasheets are in Chinese.

No worries, thanks @skot for confirming that jlcpcb do not stock all parts.

Closed 2024-02-25.

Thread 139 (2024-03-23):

SELF TEST FAIL, NO CHIPS DETECTED

Ivanverdonck, 2024-03-23:
Hello,

I have my Bitaxe made by PcbWay. But it seems not to be working:

ESP-ROM:esp32s3-20210327
Build:Mar 27 2021
rst:0x15 (USB_UART_CHIP_RESET),boot:0x28 (SPI_FAST_FLASH_BOOT)
Saved PC:0x4037b8b2
SPIWP:0xee
mode:DIO, clock div:1
load:0x3fce3818,len:0x16e0
load:0x403c9700,len:0x4
load:0x403c9704,len:0xc00
load:0x403cc700,len:0x2eb0
entry 0x403c9908
I (27) boot: ESP-IDF v5.1 2nd stage bootloader
I (27) boot: compile time Mar  3 2024 19:55:36
I (27) boot: Multicore bootloader
I (30) boot: chip revision: v0.2
I (34) boot.esp32s3: Boot SPI Speed : 80MHz
I (38) boot.esp32s3: SPI Mode       : DIO
I (43) boot.esp32s3: SPI Flash Size : 16MB
I (48) boot: Enabling RNG early entropy source...
I (53) boot: Partition Table:
I (57) boot: ## Label            Usage          Type ST Offset   Length
I (64) boot:  0 nvs              WiFi data        01 02 00009000 00006000
I (72) boot:  1 phy_init         RF data          01 01 0000f000 00001000
I (79) boot:  2 factory          factory app      00 00 00010000 00400000
I (87) boot:  3 www              Unknown data     01 82 00410000 00300000
I (94) boot:  4 ota_0            OTA app          00 10 00710000 00400000
I (101) boot:  5 ota_1            OTA app          00 11 00b10000 00400000
I (109) boot:  6 otadata          OTA data         01 00 00f10000 00002000
I (117) boot:  7 coredump         Unknown data     01 03 00f12000 00010000
I (124) boot: End of partition table
I (128) boot: Defaulting to factory image
I (133) esp_image: segment 0: paddr=00010020 vaddr=3c0b0020 size=2a954h (174420) map
I (173) esp_image: segment 1: paddr=0003a97c vaddr=3fc98100 size=04bbch ( 19388) load
I (177) esp_image: segment 2: paddr=0003f540 vaddr=40374000 size=00ad8h (  2776) load
I (179) esp_image: segment 3: paddr=00040020 vaddr=42000020 size=a73ech (685036) map
I (310) esp_image: segment 4: paddr=000e7414 vaddr=40374ad8 size=13614h ( 79380) load
I (336) boot: Loaded app from partition at offset 0x10000
I (337) boot: Disabling RNG early entropy source...
I (348) cpu_start: Multicore app
I (348) cpu_start: Pro cpu up.
I (349) cpu_start: Starting app cpu, entry point is 0x40375584
I (0) cpu_start: App cpu up.
I (367) cpu_start: Pro cpu start user code
I (367) cpu_start: cpu freq: 160000000 Hz
I (367) cpu_start: Application information:
I (370) cpu_start: Project name:     esp-miner
I (375) cpu_start: App version:      v2.1.3
I (380) cpu_start: Compile time:     Mar 18 2024 01:00:33
I (386) cpu_start: ELF file SHA256:  458b5eb513f460e4...
I (392) cpu_start: ESP-IDF:          v5.1
I (396) cpu_start: Min chip rev:     v0.0
I (401) cpu_start: Max chip rev:     v0.99
I (406) cpu_start: Chip rev:         v0.2
I (411) heap_init: Initializing. RAM available for dynamic allocation:
I (418) heap_init: At 3FCA2460 len 000472B0 (284 KiB): DRAM
I (424) heap_init: At 3FCE9710 len 00005724 (21 KiB): STACK/DRAM
I (431) heap_init: At 3FCF0000 len 00008000 (32 KiB): DRAM
I (437) heap_init: At 600FE010 len 00001FF0 (7 KiB): RTCRAM
I (444) spi_flash: detected chip: gd
I (447) spi_flash: flash io: dio
W (452) ADC: legacy driver is deprecated, please migrate to `esp_adc/adc_oneshot.h`
I (460) sleep: Configure to isolate all GPIO pins in sleep state
I (467) sleep: Enable automatic switching of GPIO sleep configuration
I (474) app_start: Starting scheduler on CPU0
I (479) app_start: Starting scheduler on CPU1
I (479) main_task: Started on CPU0
I (489) main_task: Calling app_main()
I (529) miner: NVS_CONFIG_ASIC_FREQ 485.000000
I (529) miner: ASIC: BM1366
I (529) self_test: I2C initialized successfully
I (529) DS4432U.c: Set ASIC voltage = 1.200V [0xC6]
I (539) DS4432U.c: Writing 0xC6
I (539) self_test: OLED init success!
I (559) DS4432U.c: DS4432U+ OUT1 = 0xC6
I (559) serial: Initializing serial
I (559) bm1366Module: Initializing BM1366
I (1769) bm1366Module: 0 chip(s) detected on the chain
final refdiv: 2, fbdiv: 233, postdiv1: 6, postdiv2: 1, min diff value: 0.416656
I (1799) bm1366Module: Setting Frequency to 485.00MHz (0.01)
I (1799) self_test: 0 chips detected
I (1799) bm1366Module: Setting max baud of 1000000
I (1819) serial: Changing UART baud to 1000000
I (2819) self_test: Sending work
E (2819) self_test: SELF TEST FAIL, NO CHIPS DETECTED

Is there a way to test if the chip is OK? Is someone having the same issue?

Kind regards.

skot, 2024-03-23:
This seems like a build issue. Probably the ASIC solderin. Can you please bring this up on the OSMU discord help channel? https://osmu.bitaxe.org

Closed 2024-03-23.

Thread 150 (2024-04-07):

Replace 10v caps with 16v

benjamin-wilson, 2024-04-07:
For greater compatibility with the hex, use 16v caps

benjamin-wilson, 2024-04-07:
Completed.

Closed 2024-04-07.

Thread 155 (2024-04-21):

Nonce Difficulty is always 0.00

weixiongmei, 2024-04-21:
Hi, suddenly the Bitaxe always returning Nonce Difficulty 0.00, I have replaced a new BM1366AL chip, but still facing the same issue, RX Job ID is always 40, and nonce difficulty is always 0.00.... And here's the log

```
₿ (3884) bm1366Module: 1 chip(s) detected on the chain
₿ (4182) bm1366Module: Setting Frequency to 400.00MHz (0.01)
₿ (4196) stratum_task: Get IP for URL: americas.mining-dutch.nl
₿ (4197) bm1366Module: Setting max baud of 1000000
₿ (4212) stratum_task: Connecting to: stratum+tcp://americas.mining-dutch.nl:9996 (15.235.43.55)
₿ (4222) serial: Changing UART baud to 1000000
₿ (4222) stratum_task: Socket created, connecting to 15.235.43.55:9996
₿ (4228) ASIC_task: ASIC Ready!
₿ (4198) main_task: Returned from app_main()
₿ (4272) bm1366Module: RX Job ID: 40
₿ (4273) bm1366Module: Invalid job nonce found, id=64
₿ (4276) stratum_api: tx: {"id": 1, "method": "mining.subscribe", "params": ["bitaxe/BM1366"]}
₿ (4319) stratum_api: Received result {"id":1,"result":[[["mining.notify","0437c817"]],"0437c817",4],"error":null}
₿ (4321) stratum_api: tx: {"id": 2, "method": "mining.configure", "params": [["version-rolling"], {"version-rolling.mask": "ffffffff"}]}
₿ (4364) stratum_api: Received result {"id":2,"result":{"version-rolling":true,"version-rolling.mask":"1fffe000"},"error":null}
₿ (4366) stratum_api: Set version mask: 1fffe000
₿ (4371) stratum_api: tx: {"id": 3, "method": "mining.suggest_difficulty", "params": [1000]}
₿ (4382) stratum_api: tx: {"id": 4, "method": "mining.authorize", "params": ["Miner.Bitaxe1", "x"]}
₿ (4410) stratum_task: rx: {"id":3,"result":true,"error":null}
₿ (4412) stratum_task: message result accepted
₿ (5035) bm1366Module: RX Job ID: 40
₿ (5037) bm1366Module: Invalid job nonce found, id=64
₿ (5815) stratum_task: rx: {"id":4,"result":true,"error":null}
₿ (5817) stratum_task: message result accepted
₿ (5870) stratum_task: rx: {"id":null,"method":"mining.set_difficulty","params":[65536]}
₿ (5872) stratum_task: Set stratum difficulty: 65536
₿ (5919) stratum_task: rx: {"id":null,"method":"mining.notify","params":["4254432d63613565-477","b29c7d86b203c9a2f75ed2e4dbe072dcef0d555f000267cc0000000000000000","01000000010000000000000000000000000000000000000000000000000000000000000000ffffffff540338d20c047f74256608fabe6d6dd60cf2c8ee21d6b88677da5ecc5050decc436c7e72648ce0e5a44d6878f0da9a0001000000000000","dd01132f4d696e696e672d44757463682f2d31303530000000000239c33325000000001976a91469fbaccdeb336694dca0b696ee0795d201a04d2788ac0000000000000000266a24aa21a9edbccaa622fc4f9893c5e575e06c48a5503f445aca01477f2b81bc472519904ff000000000",["473e726178cae48e3f62d07c9c666326b4fe72f61b3bead2393cc6c119f27593","b7dfbe9ebe86d9e49a6121f457534f93e0754c5559e63bb7ea35305a3ee64b5a","3c9193107941f1a84a5ddf281e403956e42607642a073a8fb2d33fa7cb7aa1ff","525cc86dc8eafea77b3f5185b35cf5d1925043406abcc8870242b809dc5fa495","200a51355022f5a9bea87b58580a123b513f7a8f1735d655279c6d6a45744b48","b9e3b2a520f5383d44a0cee849595a75fc5c6dfd5ece2261d7dfd7554ae09ef2","38483928ff4ce079b36d92be43ba7c72d1fe1e9f4a605193ec9b82063b563dc3","c204e9d9e2d185ca162b6152f9e52ab4e5e10ba27bb6e285bf3582e3a15abad1","f0791083c43ea8bc1210b8fe21dc20a8ecf5d2f359e41ef8adfa85909a61972c","51d16ee9aaaace095c59f76aafe4ed875b813884bc038369ff709cba27036b78","eca619e3f321ce7510b65b8d3d180bf3859dbe56f475b541e62c9943e40d470b","650523b5c4551bdfb587b21efe6c20f508e45e7d02aff2d0bf3d061c2a9d3d60"],"20000000","17034219","6625747e",true]}
₿ (6035) SystemModule: Syncing clock
₿ (6039) create_jobs_task: New Work Dequeued 4254432d63613565-477
₿ (6512) stratum_task: rx: {"id":null,"method":"mining.notify","params":["53504143452d63613533-478","d90b8887725e699838dca2e95cc14e8a78970b87016b0d8d0000000000000000","01000000010000000000000000000000000000000000000000000000000000000000000000ffffffff5403f10501046774256608fabe6d6dd60cf2c8ee21d6b88677da5ecc5050decc436c7e72648ce0e5a44d6878f0da9a0001000000000000","de01132f4d696e696e672d44757463682f2d31303530000000000104dd1b95000000001976a914c9b7843dc2bc3d7c9b1b0c6221d0982ab4f6ba3188ac00000000",["57d4e69e22b436ba4a73dc0d702b6dffb949ba33e220dc4a2b8d0e465388a0a5","dd1a4f90c13231ac69eb6d5e933ee591cc6c968bc7c6ca5036844d61c04d28b3","9d97833c7be2535a51189731062dd619ad386891fa7a079e1052bbde57fc2d36","aa30e0161465c42b5a609c2a160827d60c6675831c15ade1063aa1d58131d199","ba26972b625810b62612c1006d7205ba6a2a165327d8700c7f1ffb6a271466c2","08d1b777bb3f7b3327d0db4b5477c00299fc01f0f54197cb2c76b9d72426633e","eaa7d4841388e9a90fcfa4b76cc93e2a18ce25df37ebe933e02232c14c19740f"],"20000000","180b4d57","66257467",true]}
₿ (6592) stratum_task: abandoning work
₿ (6595) create_jobs_task: New Work Dequeued 53504143452d63613533-478
₿ (7269) bm1366Module: RX Job ID: 40
₿ (7271) bm1366Module: Invalid job nonce found, id=64
₿ (7844) stratum_task: rx: {"id":null,"method":"mining.notify","params":["53504143452d63613633-478","d90b8887725e699838dca2e95cc14e8a78970b87016b0d8d0000000000000000","01000000010000000000000000000000000000000000000000000000000000000000000000ffffffff5403f10501048574256608fabe6d6db076ba75403c793134ed6b9f9d7186315f8ead772b43846ecab7e13fa0ddd20e0001000000000000","de01132f4d696e696e672d44757463682f2d31303530000000000104dd1b95000000001976a914c9b7843dc2bc3d7c9b1b0c6221d0982ab4f6ba3188ac00000000",["57d4e69e22b436ba4a73dc0d702b6dffb949ba33e220dc4a2b8d0e465388a0a5","dd1a4f90c13231ac69eb6d5e933ee591cc6c968bc7c6ca5036844d61c04d28b3","9d97833c7be2535a51189731062dd619ad386891fa7a079e1052bbde57fc2d36","aa30e0161465c42b5a609c2a160827d60c6675831c15ade1063aa1d58131d199","ba26972b625810b62612c1006d7205ba6a2a165327d8700c7f1ffb6a271466c2","08d1b777bb3f7b3327d0db4b5477c00299fc01f0f54197cb2c76b9d72426633e","eaa7d4841388e9a90fcfa4b76cc93e2a18ce25df37ebe933e02232c14c19740f"],"20000000","180b4d57","66257485",false]}
₿ (7893) bm1366Module: RX Job ID: 40
₿ (7927) bm1366Module: Invalid job nonce found, id=64
₿ (8187) create_jobs_task: New Work Dequeued 53504143452d63613633-478
₿ (8742) bm1366Module: RX Job ID: 40
₿ (8743) bm1366Module: Invalid job nonce found, id=64
₿ (10203) bm1366Module: RX Job ID: 40
₿ (10205) bm1366Module: Invalid job nonce found, id=64
₿ (10950) bm1366Module: RX Job ID: 40
₿ (10952) bm1366Module: Invalid job nonce found, id=64
₿ (11686) bm1366Module: RX Job ID: 40
₿ (11688) bm1366Module: Invalid job nonce found, id=64
₿ (12414) bm1366Module: RX Job ID: 40
₿ (12416) bm1366Module: Invalid job nonce found, id=64
₿ (13152) bm1366Module: RX Job ID: 40
₿ (13154) bm1366Module: Invalid job nonce found, id=64
₿ (14605) bm1366Module: RX Job ID: 40
₿ (14607) bm1366Module: Invalid job nonce found, id=64
₿ (15332) bm1366Module: RX Job ID: 40
₿ (15334) bm1366Module: Invalid job nonce found, id=64
₿ (16796) bm1366Module: RX Job ID: 40
₿ (16797) bm1366Module: Invalid job nonce found, id=64
₿ (18251) bm1366Module: RX Job ID: 40
₿ (18253) bm1366Module: Invalid job nonce found, id=64
₿ (21870) bm1366Module: RX Job ID: 40
₿ (21872) asic_result: Nonce difficulty 0.00 of 65536.
₿ (23328) bm1366Module: RX Job ID: 40
₿ (23330) asic_result: Nonce difficulty 0.00 of 65536.
₿ (24759) bm1366Module: RX Job ID: 40
₿ (24761) asic_result: Nonce difficulty 0.00 of 65536.
₿ (25357) bm1366Module: RX Job ID: 40
₿ (25359) asic_result: Nonce difficulty 0.00 of 65536.
₿ (25982) bm1366Module: RX Job ID: 40
₿ (25984) asic_result: Nonce difficulty 0.00 of 65536.
₿ (25991) bm1366Module: RX Job ID: 40
₿ (25993) asic_result: Nonce difficulty 0.00 of 65536.
₿ (25998) bm1366Module: RX Job ID: 40
₿ (26000) asic_result: Nonce difficulty 0.00 of 65536.
₿ (26002) bm1366Module: RX Job ID: 40
₿ (26007) asic_result: Nonce difficulty 0.00 of 65536.
₿ (26013) bm1366Module: RX Job ID: 40
₿ (26017) asic_result: Nonce difficulty 0.00 of 65536.
₿ (26023) bm1366Module: RX Job ID: 40
₿ (26027) asic_result: Nonce difficulty 0.00 of 65536.
₿ (26033) bm1366Module: RX Job ID: 40
₿ (26038) asic_result: Nonce difficulty 0.00 of 65536.
```

skot, 2024-04-22:
This is most likely a soldering issue. Please use the OSMU Discord https://discord.gg/osmu for build help.

Closed 2024-04-22.

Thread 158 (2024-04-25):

Change Barrel Plug Jack to 54-00164/DC050-T

benjamin-wilson, 2024-04-25:
While the PJ-036AH-SMT-TR has lots of stock on DigiKey, it's expensive ($1.01900 vs $0.62620), experiences issues during reflow where the 3rd leg does not make contact and has a large, unusual footprint.

The 54-00164 has more limited availability but is widely available on LCSC https://www.lcsc.com/product-detail/DC-Power-Connector_SHOU-HAN-DC050-T_C431534.html bagged for $0.072 (verified correct size on datasheet and in-hand despite incorrect listing)

skot, 2024-04-26:
the 54-00164 footprint in the bitaxe library was corrupt. I grabbed a new one from Digikey / SnapEDA

Closed 2024-06-07.

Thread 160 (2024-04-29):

Switch EMC2101 to ESP32 PWM

korbin, 2024-04-29:
To save cost, complexity, and a unique component:

- Pull fan PWM to 5V (board gets plugged in, fan goes to 100%)
- Add additional level shifter (TXU0304 or TXU0202) from 3V3 -> 5V
- Use ESP32 PWM signal to drive level shifter (or MOSFETs) to set fan speed
- Use ESP32 PWM counter/GPIO/timer/whatever peripheral to measure fan speed

skot, 2024-05-02:
I like this idea for if/when we don't need the EMC2101 for temp diode reading anymore. Supposedly the BM1368 has the ability to read the temp (and voltage) out over there serial port. This needs a little more hacking/dev to get working

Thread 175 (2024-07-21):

Ultra207 - need to fix power suppily for BM1366. It take 1.8V and 0.8V. Not 1.2V

aaron3481, 2024-07-21:
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

ztbupt, 2024-10-27:
Hi, to be more clear. 1.2V is correct or 1.8V is correct?

there is a note from that page:
https://osmu.wiki/osmu-lab/bm1366
 VDDIO_18_0 | 1.8V IO voltage (this is normally 1.2V now)

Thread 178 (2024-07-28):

402 - R2,R3 and R4

Alexgtc, 2024-07-28:
In the gabers come the resistors r2,r3 and r4 but the list of materials do not come. Do you know if they are necessary and if so, what value do they have to have

19201003080114, 2024-07-28:
If not in BOM, assume DNP

Alexgtc, 2024-07-28:
What is DNP? Do you mean that if it's not on the list, don't put them? Would it work well then without putting those resistances?

19201003080114, 2024-07-28:
DNP is Do No Populate. You leave them empty.
If you want to be sure, check the schematics.

Alexgtc, 2024-07-28:
Where can you find the diagrams of the supra 402 bitaxe plate?

19201003080114, 2024-07-28:
https://github.com/skot/bitaxe/tree/supra-402

402 is not ready. Yes 401

Alexgtc, 2024-07-28:
What is missing from the plate to be finished? With the current bom list and the current gabers it doesn't work?

skot, 2024-07-28:
Please only use issues for bugs. For assembly help please ask on the OSMU Discord

Closed 2024-07-28.

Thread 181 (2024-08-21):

"DEVICE OVERHEATED" message retained on display after updating settings, cooling, and restarting

satscoffee, 2024-08-21:
My device overheated...unsure why but it did but seemed to shut down before causing damage.

 I was using the default settings but was moving the device around to stop the fan from vibrating. Regardless, it overheated and stopped hashing. I went to the webUI as directed and updated the settings back to default and saved. I unplugged the device and let it cool down to room temperature.

When plugging Bitaxe back in and starting up, it was hashing correctly but the display still toggles back and forth of showing the hash rate, but also saying "DEVICE OVERHEATED" for a bit before toggling back to the hash. Below that, the message of "Please check webUI for more information" remains on the display continuously.

Current Setup:
Device: Bitaxe 401 Supra
Latest Release: v2.1.10
Frequency: 490
Voltage: 1166
Current Hash: 667.61 Gh/s
Power: 13.1W
Voltage: 5V
ASIC Voltage Requested: 1.17V
ASIC Temperature: 55C
Fan: 56%
ASIC Frequency: 490Mhz
ASIC Voltage Measured: 1.19V

Still haven't mined any blocks. Should I add this as another issue haha.

19201003080114, 2024-08-26:
Watch the WantClue video on YouTube on how to reset overheat message.

OsO-1973, 2024-08-26:
Same problem here, can u put up a link as I don’t find the video
Thx in advance

benjamin-wilson, 2024-08-26:
Please reach out to the seller for support, GitHub is for issues with the project and not after sales support.

OsO-1973, 2024-08-26:
Thx Benjamin for the swift answer, it is about the project imho as there was no explanation how to reset it
Found it myself
https://youtu.be/wlHHc9InK6w?si=Jp54Zd3egflS9TRU  at exactly 07:30 min how to reset the message as there is no written documentation
Now it is completed
Cheers
OsO

satscoffee, 2024-08-26:
After watching the video, there is definitely a bug as my webUI did not/does not have the "Disable overheat mode" checkbox.

I just forced the Bitaxe to overheat again by lowering the fan and confirmed again there is not a checkbox after reviewing the webUI.

Running Latest Release: v2.1.10 but it's possible the overheat initially happened on the prior version, then I upgraded to the new firmware before resetting the frequency and voltage.

OsO-1973, 2024-08-26:
You have to update the webgui (download www.bin) then throttle the fan , it will overheat > then it appears like in the video and then the checkmark disappears.
Shd be solved then
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

19201003080114, 2024-08-26:
Do you have latest www.bin installed?

satscoffee, 2024-08-26:
Thank you! Done. It worked

Closed 2024-08-26.

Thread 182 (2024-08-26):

Bitaxe Supra 401 unresponsive after attempting upgrade via the OS

kinsaledunny, 2024-08-26:
Hi everyone,

I hope its ok to piggyback on this thread. I recently purchased a bitaxe Supra 401. I set it up and it was hashing away for me. I went to update the firmware and the device seems to have bricked on me. The screen has gone blank, I can boot it up and the fan spins but I'm unable to connect to it. I have tried to re-flash from https://wantclue.github.io/bitaxe-web-flasher/ on my COM1 & COM3 ports
but I keep getting the following message "Failed to initialize. Try resetting your device or holding the BOOT button while clicking INSTALL." I have pressed the reset button while pressing install but the fan stopped and the install failed, I have also tried to press the boot button while pressing install but nothing happens.
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

I have also tried to flash from https://flasher.bitronics.store/ and I'm getting the following error message "Starting flash process...
Error connecting to chip: Error: Failed to connect with the device
Fetching: assets/bitaxe_1.0.0/bootloader.bin
Failed to fetch or process file bootloader.bin: Error: HTTP error! status: 404 for file bootloader.bin"
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

Any help would be greatly appreciated. Thanks in advance guys.

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
kinsaledunny, 2024-08-26:
Hi guys, thanks for getting back to me so quickly. I have downloaded fix.zip but I'm getting the following error when trying to extract the file
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

2302114245, 2024-08-26:
> 嗨，伙计们，感谢您这么快回复我。我已下载fix.zip但在尝试提取文件时收到以下错误 ![图像](https://private-user-images.githubusercontent.com/179467925/361434865-2766f6cf-44ab-4eca-8544-8668ce60728b.png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)

Not deleting it, it's a number-stealing virus I sought help in other communities leading me to download this!

19201003080114, 2024-08-26:
This is simply because you didn’t put device in bootloader mode before flashing.
Why would you randomly download files from unknown source and run it?
You don’t need to download any files to fix this simple issue.
Check your computer now for virus and malware.

benjamin-wilson, 2024-08-26:
> Hi guys, thanks for getting back to me so quickly. I have downloaded fix.zip but I'm getting the following error when trying to extract the file ![image](https://private-user-images.githubusercontent.com/179467925/361434865-2766f6cf-44ab-4eca-8544-8668ce60728b.png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)

This is some sort of virus/malware. Id suggest reinstalling your OS.

benjamin-wilson, 2024-08-26:
Please reach out to the seller for help. GitHub is for issues with the project and not individual support.

Closed 2024-08-26.

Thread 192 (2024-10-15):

Bitaxe supra self test monitor fail

MabsHA, 2024-10-15:
my bitaxe wasn’t hashing anymore after i installed the 2.2.2 firmware i downgraded to the 2.1.10 still didn’t work. i reflashed with the webflasher New Bitaxe Supra: Board Version 401 (factory)V2.1.10 but now i get message (monitor fail) after self test with serial readings i get this message (self_test: INA260 test failed!) ill ad log download.

any ideas?
[esp-web-tools-logs.1.txt](https://github.com/user-attachments/files/17379525/esp-web-tools-logs.1.txt)

19201003080114, 2024-10-15:
Likely you have a hardware failure, and not software related.

MabsHA, 2024-10-15:
> Likely you have a hardware failure, and not software related.

Can it be fixed?

MabsHA, 2024-10-15:
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

That's only €2,50 I'll try

skot, 2024-10-15:
Github issues are not for build issues. please use OSMU.

MabsHA, 2024-10-15:
Where can I find that?

skot, 2024-10-15:
https://discord.gg/osmu

MabsHA, 2024-10-15:
And I didn't know if it was firmware or hardware sorry

Closed 2024-10-15.

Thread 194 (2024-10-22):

My new Bitaxe Gamma 0.00 H/s

JCF711, 2024-10-22:
Try with diferent internet connections, and diferents Pools. V.2.3.0

₿ (1137946) stratum_task: Clean Jobs: clearing queue
₿ (1138956) stratum_task: Connecting to: stratum+tcp://public-pool.io:21496 (172.234.17.37)
₿ (1138956) stratum_task: Socket created, connecting to 172.234.17.37:21496
₿ (1139076) stratum_api: Resetting stratum uid
₿ (1139076) stratum_task: Clean Jobs: clearing queue
₿ (1139076) stratum_api: tx: {"id": 1, "method": "mining.subscribe", "params": ["bitaxe/BM1370/v2.3.0"]}
₿ (1139086) stratum_api: tx: {"id": 2, "method": "mining.configure", "params": [["version-rolling"], {"version-rolling.mask": "ffffffff"}]}
₿ (1139106) stratum_api: tx: {"id": 3, "method": "mining.authorize", "params": ["xxxxxxxxxxxxxxxxxxxxxxxxxxxxxxxxxxx", "x"]}
₿ (1139116) stratum_api: tx: {"id": 4, "method": "mining.suggest_difficulty", "params": [1000]}
₿ ### (1139286) **stratum_task: rx: {"id":1,"error":null,"result":[[["mining.notify","57601348"]],"57601348",4]}**
₿ (1139286) stratum_api: extranonce_str: 57601348
₿ (1139296) stratum_api: extranonce_2_len: 4
₿ (1139376) **stratum_task: rx: {"id":2,"error":null,"result":{"version-rolling":true,"version-rolling.mask":"1fffe000"}}**
₿ (1139376) stratum_api: Set version mask: 1fffe000
₿ (1139376) stratum_task: Set version mask: 1fffe000
₿ (1139386) **stratum_task: rx: {"id":3,"error":null,"result":true}**
₿ (1139396) stratum_task: setup message accepted
₿ (1139396) stratum_task: rx: {"id":null,"method":"mining.set_difficulty","params":[1000]}
₿ (1139416) stratum_task: rx: {"id":null,"method":"mining.notify","params"

Result, 0.00 Hash Rate

skot, 2024-10-22:
Despite what it looks like, there are no errors here. Please contact the seller, or use OSMU (discord.gg/osmu) for support.

billytaylor, 2024-10-24:
@JCF711 I noticed that my Gamma was 0.00H/s too after I had updated the asic freq to '525 (default)' in the web UI. I set it down to 490 and it's hashing happily again now. HTH, cheers

JCF711, 2024-10-24:
In the end it was an overheating problem. When the protection was triggered the voltage was set to 1000, and I set the frequency to 525Mhz (by default), and so it couldn't mine. The thing is that I can only use it at 400Mhz (voltage >1050) so it doesn't overheat (and even then it stops every 3-4 hours). I'm going to change the thermal paste for a specific one for 'ASIC' and I'll see if I can solve the problem.

Closed 2024-10-22.

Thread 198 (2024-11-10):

SELF TEST FAIL, INCORRECT CORE VOLTAGE

sospcie, 2024-11-10:
Hi All,

Finally I was able to build my Bitaxe Gamma device with BM1370BC. Was not easy but was fun. :)

Flashed the firmware, display working, fan spinning, logs display the chip detected, but then I get this message on screen and in the terminal as well

self_test: SELF TEST FAIL, INCORRECT CORE VOLTAGE

Does anyone can give me a hint which of the chip responsible for the CORE VOLTAGE?

Thank you

19201003080114, 2024-11-11:
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

benjamin-wilson, 2024-11-11:
Github is not the right place for troubleshooting individual issues, this is for fundamental issues with the project.

Visit https://discord.gg/osmu for help.

Closed 2024-11-11.

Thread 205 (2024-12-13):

RPM value is null

alltheseas, 2024-12-13:
_what happens_

RPM displays zero ("0 RPM"), when %fan speed is non-zero, and I can see and hear the fan spinning.

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

_device & settings_

gamma 601 gekkoscience
2.4.1 firmware & website

alltheseas, 2024-12-13:
sidehack advises:

> Likely the fan isn't reporting RPM, so hardware not software

How might we handle unhappy path of fans that do not return data needed to calculate RPM?

alltheseas, 2024-12-13:
Is it possible to not display RPMs field if fan is not returning data needed for RPM calculation?

19201003080114, 2024-12-13:
> Is it possible to not display RPMs field if fan is not returning data needed for RPM calculation?

What is the benefit?
It complicates the codes, and you will not see any signs of issues if a previously working fan reporting RPM suddenly stops reporting.
If the register value is 0, show it as 0 so there is no confusion what it is at.

alltheseas, 2024-12-13:
> What is the benefit?

By removing useless visual elements, clarity improves and focus falls on the useful elements. Conversely, if you dont remove useless elements, and do not simplify, the useful elemen ts will be muddled with useless elements.

> you will not see any signs of issues if a previously working fan reporting RPM suddenly stops reporting.

This is potential unhappy path you have identified. If there is such an error, it should be surfaced to the bitaxe enjoyer. This does not preclude removing a metric that is useless for hardware that do not support reporting the relevant info.

> I don't see anything wrong the way it is now.

For you, and the current Bitaxe enjoyers there is no problem, probably.

What is the mission of Bitaxe? If it is to distribute mining and make it accessible to more folks than the current set simplification, and ease of use matters.

If you'd like to learn more about UI and usability, nngroup has great resources:

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
https://www.nngroup.com/articles/ten-usability-heuristics/

19201003080114, 2024-12-13:
> By removing useless visual elements, clarity improves and focus falls on the useful elements. Conversely, if you dont remove useless elements, and do not simplify, the useful elemen ts will be muddled with useless elements.

It is better to report the values are they are, or don't report at all.
Selectively hiding them only confuses users.
No software has ever implemented fan UI like you suggested.
Look at fan UI for mobos or any other implementation.
If fan speed is 0, display 0 or N/A.
If the value is hidden, users cannot know what is happening.

I think the UI now is fine for the fans. No need to change.
If you want to, source code is available for you to make the change yourself.

alltheseas, 2024-12-13:
It could be that hardware dashboard UI cannot be simplified past the current state.

Consider it a design challenge.

skot, 2024-12-13:
I do think there is some room for improvement here. We need to express the setpoint (74% in this case) and the actual measured value (0 RPM in this case). and then someway to show that the fan is not working. @alltheseas can you think of a better way to express this? We need to appear to technical users and new users alike.

alltheseas, 2024-12-13:
@skot do yall have a design contributor?

As a left-curve product contributor I can put together wireframes, and low fidelity mockups, and I know expert design is not my skillset. I might miss the trees for the forest with any design suggestions I conjure beyond problem statements.

For example on Damus we have the great @robagreda contributing designs, and we've had a few design pros from Bitcoin Design Community contribute reviews and piecemeal suggestions as well.

Outside of the specific question at hand, I think if there is no design contributor, it would be a fun exercise to organize a design challenge for AxeOS with the pretext of "how might we improve usability of AxeOS, as to reduce to the barrier of wider mining adoption".

Let me know if this sounds interesting, happy to test interest from designers, and help organize.

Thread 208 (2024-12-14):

Troubleshooting BitaxeMax 2.3

Lysnyt, 2024-12-14:
Hello guys, i believe someone can help me to figure this out.
I tried to assemble the second bitaxe - bitaxe max with bm1397.

I can´t get it to work, i have tried many firmware versions from 2.1.1 to latest 2.4.1.
I have tried default mining pool for troubleshooting (i dont know if there is any password, i typed "x")
But i get from the realtime log everytime "₿ (57233) bm1397Module: return null"
The BM1397 was new, i have 5 others bitaxe max with same error, with differnet completely new BM1397.
Voltage ok > 5V > 3.3V >1.8V > 0.8V.
I have registered huuuge voltage drop (0,8V like there was a diode)on input after start. I have Riden 18A 60V power supply.
If i raise the voltage to 5.8V, so it will show 5V voltage in the web interface, i´m worrying about INA260 which has in datasheet supply voltage to 5.5V.

Workaround:
Bitaxe Max, which was outdated every since a no one did any update to final design (that one with usb connector).
First i did assemble the outdated version 2.3 without usb connector, which was pain in the ass, as i wanted to upload the firmware with standard usb to ttl bridge (which are we using in work). Somehow i managed to get it done (that it was no webflasher), but nothing worked (no connection). I am electrician, very bad one, but i can do many simple things and i understand basics. We have used in work essemtec pick and place machine, we do industrial measuring devices (level sensors, thermometers, pressure,..) with mainly 0603 parts, so this 0402 parts in big DPS with dozen of space get me no sense. In my point of view, the design is oriented as developing board, as there are dozens TPoints, 2 JTag and another 2 rows of VIAs for future use.. Skot as father of this project did great work, but maybe it is time to make it more simple if there is will.
In the way of the assembly i see flaws like incomplete BOM list (capacitors without voltage requirements, inductance without specifications, outdated github page for any branch, no wiki for troubleshooting or "how to", ..
Many times i have time to help You with this (and i believe other people too) and update anything wrong i get upon, but there is now instruction how to do it.

Log:
₿ (57233) bm1397Module: return null
₿ (64663) stratum_task: rx: {"params":["67444bb00000e114","e15c9930d787926e5218d5e966591831743546170000a1790000000000000000","01000000010000000000000000000000000000000000000000000000000000000000000000ffffffff3503db580d0004245f5d670473bbfb080c","0a636b706f6f6c112f736f6c6f2e636b706f6f6c2e6f72672fffffffff03a16e9a1200000000220020984a77c289084ff2d434c316bdada021c6c183d507c8a20d3b159b09ac02fe28473161000000000016001451ed61d2f6aa260cc72cdf743e4e436a82c010270000000000000000266a24aa21a9ed9054f8df3080516fc74e7be17f6102b7fddd45033198b0771cf9ce8b113d4dc200000000",["898eb5e1fee3a67fab7b9dc2c3cb829f6b4de8475d25c93af1a476ee622df497","5064f033c5b0fd0f42b2f7d99ea39c53f2f6bee8800ed037e9d1e0070928655c","01d69b652f31b7b62ef94bee1175eb93b11585821766bb81f8e7921f132b6bb1","a001a7a9f55aa2b347746efe7de27cbf96f581d789af264b3091a3996bc7c597","b0bb88f12e2f7c1c0e89d82dc4c027aab2f9708c7d3db104645a9b965becad60","4acb5297a9fdaf688558d4ccd88814b92e2a7324149028cc91e026c502498421","5220f1c12b8e280b628bee2bf8f727be2ee5064243ea3f5450766928ef30f06b","9adde7cb903d82c44ac4f93157f1945f7d9d5226bc3c5f6f8372ed993ce2854e","7a227f7f7f37153f6e7022a664c8c5454352c19c8b5624521c163e642a7c89ea","eaf00f4848d051780566467c419202886aa9d06a959c9c8873ccba5b7a54cc31","e3a256026b32739192dc9bc80a18fcd1574a8a4be42bd827f2ee49361b302e9b","26a682cb5a7cb36b7652e083ac75929ae77239473220ccbb96b723236864d54d"],"20000000","1702b563","675d5f24",false],"id":null,"method":"mining.notify"}
₿ (64793) create_jobs_task: New Work Dequeued 67444bb00000e114
₿ (64793) create_jobs_task: Job processed and queued: 67444bb00000e114
₿ (67233) bm1397Module: return null
₿ (77233) bm1397Module: return null
₿ (87233) bm1397Module: return null
₿ (94743) stratum_task: rx: {"params":["67444bb00000e115","e15c9930d787926e5218d5e966591831743546170000a1790000000000000000","01000000010000000000000000000000000000000000000000000000000000000000000000ffffffff3503db580d0004425f5d670444bf90080c","0a636b706f6f6c112f736f6c6f2e636b706f6f6c2e6f72672fffffffff038c669b1200000000220020984a77c289084ff2d434c316bdada021c6c183d507c8a20d3b159b09ac02fe28563661000000000016001451ed61d2f6aa260cc72cdf743e4e436a82c010270000000000000000266a24aa21a9edddf94460917031e52a5d85e90bd03fa8ee6a2bdd56be65b53ded7d252647656400000000",["898eb5e1fee3a67fab7b9dc2c3cb829f6b4de8475d25c93af1a476ee622df497","5064f033c5b0fd0f42b2f7d99ea39c53f2f6bee8800ed037e9d1e0070928655c","01d69b652f31b7b62ef94bee1175eb93b11585821766bb81f8e7921f132b6bb1","a001a7a9f55aa2b347746efe7de27cbf96f581d789af264b3091a3996bc7c597","b0bb88f12e2f7c1c0e89d82dc4c027aab2f9708c7d3db104645a9b965becad60","e3ad9f87b16a90f628d8a14a18717becbee98b553682aa8a47251e7ca4e63754","0b70f8375beac0720e46d777d60b669fd10b3252b47343cfe3561e5e1d1e3125","2791767860cef67ec985fa5aec53eda6e6d40c5eefb1f0ebafed091536f02191","4b0fddf9dcae6787c95c959dfdb5ea08eec6a1aef4e07743fa2cb0e1c89deb89","42e58ac77c5894b0ac041dc7bb666492142c0e362f77dda07bd70a67ebabee3a","1fdbdcf3ee74e1027348524e888b12778ff9dd9c45989eeff647972a2de1e9a4","40984bd983cb94fd7933845d040ff720663041d45b0d13bf6b90f4e5d693cfdf"],"20000000","1702b563","675d5f42",false],"id":null,"method":"mining.notify"}
₿ (94893) create_jobs_task: New Work Dequeued 67444bb00000e115
₿ (94893) create_jobs_task: Job processed and queued: 67444bb00000e115
₿ (97233) bm1397Module: return null
₿ (107233) bm1397Module: return null

skot, 2024-12-14:
please use the discussions or (preferably) [OSMU](discord.gg/osmu) for troubleshooting.

Closed 2024-12-14.

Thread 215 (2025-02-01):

No Display & No WiFi on Bitaxe Supra 401 – I2C Errors

Pilotkosinus, 2025-02-01:
I'm building a Bitaxe Supra 401, and it's my first time soldering SMD components. I just finished assembling everything today. The WebFlasher worked without issues, but I’m not getting anything on the OLED display, and I don’t see a WiFi network.

I checked the serial monitor and found these errors:

```
E (1144) i2c.master: I2C transaction timeout detected
E (1234) display: No display found.
W (1234) self_test: DISPLAY not found!
E (1324) i2c_bitaxe: Device EMC2101 (0x4c)
ESP_ERROR_CHECK failed: esp_err_t 0x103 (ESP_ERR_INVALID_STATE)

```
Full serial log: https://pastebin.com/TQHnLJFt

What should I check to troubleshoot this issue? Thanks for your help!

Pilotkosinus, 2025-02-01:
I can also add that I have checked the OLED and the EMC2101 with the multimeter and both are at 3.3v.

skot, 2025-02-02:
please ask on OSMU (discord.gg/omsu) for build help.

Closed 2025-02-02.

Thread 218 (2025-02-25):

Change the algorithm ?

Uefi1, 2025-02-25:
Hi is it possible to change the outdated SHA-256 algorithm to at least SHA-256d in the firmware ? Most decent pools have been using SHA-256d for a long time now ! It would be even better if there was an option to switch the algorithm to Scrypt, Blake or RandomX for altcoins mining.

Uefi1, 2025-02-25:
> it is _impossible_ to change the algorithm on an ASIC.

Why is it impossible on ESP32? There are plenty of libraries with different algorithms, just change the code.

MyOwn2C, 2025-02-25:
> Why is it impossible on ESP32 there are plenty of libraries with different algorithms, just change the code.

Because ESP32 is a multi purpose processor, not a task specific ASIC.
ESP32 can do many things.
BM ASIC can only do one thing.

Uefi1, 2025-02-25:
> > Why is it impossible on ESP32 there are plenty of libraries with different algorithms, just change the code.
>
> Because ESP32 is a multi purpose processor, not a task specific ASIC. ESP32 can do many things. BM ASIC can only do one thing.

I have already seen that the bm1366 chip worked on altcoin algorithms and quite successfully !

MyOwn2C, 2025-02-25:
> I have already seen that the bm1366 chip worked on altcoin algorithms and quite successfully !

There are many altcpins using SHA256 so BM asics will work on them.
If you are referring to UnMineable, they only pay you in the coins you want. You still mine the algo of your ASIC.

MyOwn2C, 2025-02-25:
> No, I don’t mean anything like Unmineable. Just pure Scrypt hashing directly from the ASIC instead of SHA-256.

There are ASICS that can do Scrypt.
There are ASICS that can do SHA256.
If there is one that can do both, they are general purpose ASICs but they are terribly slow.
I think you have wrong understanding of what an ASIC is.

Uefi1, 2025-02-25:
> > No, I don’t mean anything like Unmineable. Just pure Scrypt hashing directly from the ASIC instead of SHA-256.
>
> There are ASICS that can do Scrypt. There are ASICS that can do SHA256. If there is one that can do both, they are general purpose ASICs but they are terribly slow. I think you have wrong understanding of what an ASIC is. I think you also have wrong understanding of SHA256 and Scrypt.

Look, in BitAxe, there is a BM1366 chip and an ESP32, which contains the firmware that controls the BM1366 chip. So, in the firmware, any algorithm can be implemented.

MyOwn2C, 2025-02-25:
> Look, in BitAxe, there is a BM1366 chip and an ESP32, which contains the firmware that controls the BM1366 chip. So, in the firmware, any algorithm can be implemented.

Your understanding of the system architecture of Bitaxe is completely off.

ESP32 is a processor. It sends work to BM1366 to process.

BM1366 can only do SHA256. It cannot do anything else.

This discussion is completely pointless until you understand what ESP32, BM ASICS and firmware actually can or cannot do.

If you still think it is possible, you are welcome to take the ESP-miner source code and try it itself.

Failure is a very good teacher.

Closed 2025-02-25.

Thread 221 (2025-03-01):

Bitaxe 204 - Input Voltage and Power too low. No longer hashing

aindriu18, 2025-03-01:
Last night (Feb 28), I noticed the fan on my Bitaxe made a strange noise and suddenly started to get quiet. On further investigation this morning, I noticed it has practically stopped. The fan is operational, but barely. On checking AxeOS, both power and input voltage are extremely low. Both frequency and core voltage are set to default and have been for some time. I've also made sure since day one to use the correct plug for the device.

The device is over a year old. Is it a case that it has just malfunctioned? I've tried several basic steps such as resetting it, turning it off and on, changing frequency and core voltage settings, but nothing has kicked it into gear. As of this morning, I've also updated the firmware to v2.5.0. I believe it was v2.2.0 before that.

I also notice some strange UI from AxeOS which I have included here. Note how the input voltage is in the correct location.

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

skot, 2025-03-01:
It looks like a few things have happened;

- your fan died.
- that probably caused the bitaxe to go into overheat mode.
- you haven't updated www.bin (AxeOS) so you're not seeing the warning.

Bitaxe issues is not the place for troubleshooting. Please reach out on the OSMU Discord (https://discord.gg/osmu) and we can help you get this fixed.

ST1PRO, 2025-03-02:
Hi, not sure if this happened to anyone else. But I plunged into a power strip and got a low voltage warning then later unplugged and plugged directly into the wall and the voltage warning went away.

Closed 2025-03-01.

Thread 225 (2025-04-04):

pluged 12V instead of 5V... what can i do?  yeah, the issue was caused by me... crying

Arebique, 2025-04-04:
Just like these, pluged 12V instead of 5V... what can i do? I have the tools to repair it but i really dont know where start, i cant find the voltage regulator, and im kind of new here, i just dont find the schematics also. if someone can help this future brazilian bitcoiner, i will apreciate a lot!

Wish you all the best, see yah

Arebique, 2025-04-04:
the boad dont turn on, but receive the 5v

skot, 2025-04-04:
please use the [OSMU Discord](https://discord.gg/osmu) for support questions like this.

Closed 2025-04-04.

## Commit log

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2022-05-10 updated BOM and manufacturing files
    [bitaxe-B_Cu.gbr, bitaxe-B_Mask.gbr, bitaxe-B_Paste.gbr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]
2022-05-17 change both vreg voltage divider to 100 ohm parts (and updated BOM)
    [bitaxe.kicad_pcb, bitaxe.kicad_sch]
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2022-06-10 shrink the power pads for #4 and switched the BM1387 pin pitch to 0.48mm for #5. still need to fix PCB
    [bitaxe.kicad_pcb]
2022-06-10 wired up all of the tracks to the new BM1387 footprint (for #5)
    [bitaxe.kicad_pcb]
2022-06-10 updated silkscreen for #1. Added some 1.5mm alignment pin holes in the stencil and PCB
    [bitaxe.kicad_pcb, bitaxe.kicad_sch]
2022-06-11 added VIN spade connectors for #6. moved the 5V pinheader around the corner. fixed the part numbers on R19-R22. Switched to in-stock LDOs for IC4 and IC5
    [SMV_z90.stp, bitaxe.kicad_pcb, bitaxe.kicad_sch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]
2022-06-11 added v2 BOM and gerbers
    [bitaxe BOM.xlsx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]
2022-06-11 small silkscreen touchup and regenerated gerbers
    [bitaxe BOM.xlsx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]
2022-06-15 flipped (again) C17 and C18 for #1
    [bitaxe-B_Cu.gbr, bitaxe-B_Mask.gbr, bitaxe-B_Paste.gbr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]
2022-06-17 starting the BM1397 based bitaxePro experiment
    [bitaxePro.kicad_pcb, bitaxePro.kicad_sch, bitaxePro.xlsx]
2022-06-23 made separate symbols for BM1397 in mode0 and mode1
    [DRL0006A.stp, bitaxePro.kicad_pcb, bitaxePro.kicad_sch]
2022-06-24 schematic pretty much done
    [bitaxePro.kicad_sch]
2022-06-24 added an ESP32-C3 to try out. Added a NCT218
    [bitaxePro.kicad_pcb, bitaxePro.kicad_sch]
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2022-06-27 updated readme, finished routing
    [bitaxePro.kicad_pcb]
2022-06-27 updated part numbers and generated BOM
    [bitaxe BOM.xlsx, bitaxePro BOM.xlsx, bitaxePro.kicad_sch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]
2022-10-04 switched out some OOS parts, generated BOM
    [CX3225SB16000H0FLJCC.STEP, bitaxePro BOM.xlsx, bitaxePro.kicad_pcb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]
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2022-10-12 added PCBA component position file / XY / Centroid
    [bitaxePro-all-pos.xlsx]
2022-10-12 renamed bitaxePro to bitaxeMax
    [bitaxeMax-B_Cu.gbr, bitaxeMax-B_Mask.gbr, bitaxeMax-B_Paste.gbr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]
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2022-10-24 added fix for #8. deleted manufacturing files, as they need to be re-generated
    [bitaxeMax-B_Cu.gbr, bitaxeMax-B_Mask.gbr, bitaxeMax-B_Paste.gbr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]
2022-10-24 connected osc EN pin high for #9
    [bitaxeMax.kicad_pcb, bitaxeMax.kicad_sch]
2022-10-25 added fix for #11
    [bitaxeMax.kicad_pcb, bitaxeMax.kicad_sch]
2022-11-09 bumped PCB and schematic to R2
    [bitaxeMax.kicad_pcb, bitaxeMax.kicad_sch]
2022-11-21 started adding the TPS40305
    [bitaxeMax.kicad_sch, esp32.kicad_sch, power.kicad_sch]
2022-11-22 switched over to the ESP32-S3 module. added a bunch of TODO notes
    [bitaxeMax.kicad_sch, esp32.kicad_sch, power.kicad_sch]
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2022-11-22 reset reference designators
    [bitaxeMax.kicad_pcb, bitaxeMax.kicad_sch, esp32.kicad_sch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]
2022-11-22 cleaned up some old library parts
    [bitaxeMax.kicad_pcb, bitaxeMax.kicad_sch, esp32.kicad_sch]
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2022-11-23 schematic done, all footprints added, 3D files added. Rough placement done. needs lots of routing.
    [2R5TPE220MAFB.step, DQG0008A.stp, DQH0008A.stp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]
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2022-11-25 fixed TX/RX mixup
    [esp32.kicad_sch]
2022-11-26 added almost all of the feedback from NebulaMiner
    [TXB0104RGYR.STEP, bitaxeMax.kicad_sch, bm1397.kicad_sch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]
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2022-11-27 added SN74AXC1T45 for the ESP32 clocking the BM1397 idea.
    [SN74AXC1T45DBVR.STEP, bitaxeMax.kicad_sch, bm1397.kicad_sch]
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2022-11-28 added status LEDs, GPIOs, and a bigger 3V3 LDO
    [PLCC6_LED_3_5X3_4X2_8_CRW.step, TSOT-23-5_RIT.step, bitaxeMax.kicad_pcb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]
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2022-11-30 more routing. fixed SDA/SCL short
    [bitaxeMax.kicad_pcb, bitaxeMax.kicad_sch, bm1397.kicad_sch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]
2022-11-30 lots of signals routed. much better ESP32-S3 3D model
    [ESP32-S3-WROOM-1-N8R2--3DModel-STEP-56544.STEP, bitaxeMax.kicad_pcb, bitaxeMax.kicad_sch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]
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2022-12-09 sorted out the resistor values for the DS4432. added some power filtering for the fan. created BOM
    [bitaxeMax BOM.xlsx, bitaxeMax.kicad_pcb, bitaxeMax.kicad_sch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]
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2022-12-09 oops the PCB was 1mm too tall. fixed that and re-generated gerbers
    [bitaxeMax-B_Cu.gbr, bitaxeMax-B_Mask.gbr, bitaxeMax-B_Paste.gbr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]
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2023-01-17 updated the TPS40305 feedback resistor values for #20
    [bitaxeMax BOM.xlsx, bitaxeMax.kicad_sch, esp32.kicad_sch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]
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2023-01-27 Moved LEDZ (#22) and brought JTAG pins out to debug header (#16)
    [esp32.kicad_sch]
2023-01-27 moved SCL and SDA to GPIO48 and GPIO47 for #18
    [bitaxeMax.kicad_sch, esp32.kicad_sch]
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2023-01-30 cleaned up some traces, ran DRC, moved around mounting holes, cleaned up silkscreen
    [bitaxeMax.kicad_pcb, bitaxeMax.kicad_sch, esp32.kicad_sch]
2023-01-30 switched to the standard 1.27mm pitch 10pin JTAG header
    [FTSH-105-01-F-DV-K.stp, bitaxeMax.kicad_pcb, bitaxeMax.kicad_sch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]
2023-01-30 added the JTAG connector 3D model. cleaned up a couple traces, ran DRC
    [bitaxeMax.kicad_pcb]
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2023-03-18 add note about oscillator bypass resistor. update pdf schematic
    [bm1397.kicad_sch]
2023-04-03 added manufacturer part numbers to schematic and BOM
    [bitaxeMax BOM.xlsx, bitaxeMax.kicad_sch, bm1397.kicad_sch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]
2023-05-11 removed R1 from schematic and ROM to address #42 and prolly #35
    [bitaxeMax BOM.xlsx, bm1397.kicad_sch]
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2023-05-17 fixed the DNP BOM issues
    [bitaxeMax BOM.xlsx, bitaxeMax.kicad_sch, bm1397.kicad_sch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]
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2023-06-23 components had two 'Value', thus clobbering the correct value
    [bm1397.kicad_sch, fan.kicad_sch]
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2023-07-11 added USB port and EN/BOOT buttons. placed and routed
    [USB_10118193-0001LF.STEP, bitaxeUltra.kicad_pcb, bitaxeUltra.kicad_sch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]
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2023-07-11 fixed fan default speed, got rid of ESP32 FAN_ALERT signal. DRC
    [bitaxeUltra.kicad_pcb, bitaxeUltra.kicad_sch, bm1366.kicad_sch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]
2023-07-13 switched out JLCPCB for DK parts. added gerbers, BOM
    [bitaxeMax BOM.xlsx, bitaxeUltra BOM.xlsx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]
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2023-09-05 Smaller heatsink holdes, Removed unused traces, micro USB to USB-C, C21 silkscreen
    [bitaxeUltra BOM.xlsx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]
2023-09-06 Fixed usb symbol, mounting holes
    [bitaxeUltra.kicad_pcb, bitaxeUltra.kicad_sch, esp32.kicad_sch]
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2023-09-06 Fix USB wiring
    [bitaxeUltra.kicad_pcb, esp32.kicad_sch]
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2023-09-11 moved all custom symbols and footprints to the bitaxe libraries
    [bitaxeMax.kicad_pcb, bitaxeMax.kicad_sch, esp32.kicad_sch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]
2023-09-11 moved all custom symbols and footprints to the bitaxe library
    [bitaxeUltra.kicad_pcb, bm1366.kicad_sch, esp32.kicad_sch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]
2023-09-11 fixed up USB-C wiring. added CC pulldown resistors. added LCD display to play with
    [DISST7789-176x320.STEP, bitaxeUltra.kicad_pcb, esp32.kicad_sch]
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2023-09-21 fix R10 silkscreen and update ibom
    [bitaxeUltra.kicad_pcb]
2023-10-01 Changed barrel plug to 2 pin, added JST-XH connector
    [CUI_DEVICES_PJ-037AH.step, bitaxeUltra.kicad_pcb, bitaxeUltra.kicad_sch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]
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2023-10-02 Fix screen position
    [bitaxeUltra.kicad_pcb]
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2023-10-02 switch D1 part number and moved it to (the same) KiCad footprint library. Resolved some schematic-layout sync errors.
    [bitaxeUltra.kicad_pcb, bitaxeUltra.kicad_sch, bm1366.kicad_sch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]
2023-10-02 fix JSX, updated boms
    [bitaxeUltra BOM.xlsx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]
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2023-10-11 added polarity marker for #82 updated bitaxe logo
    [bitaxeUltra.kicad_pcb, bitaxeUltra.kicad_sch, fan.kicad_sch]
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2023-10-11 added missing part numbers. updated BOM and iBOM
    [bitaxeUltra BOM.xlsx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]
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2023-10-19 moved R4 back to it's original position so I can avoid a new stencil. added OLED 3D model.
    [OLED_0.91_128x32.stp, bitaxeUltra.kicad_pcb]
2023-10-19 added some (poor) 3D models for the buttons
    [SW_CS1213AGF260_CRS.step]
2023-10-19 switched PWR_EN to GPIO10. Added 3D file for the oscillator.
    [bitaxeUltra.kicad_pcb, esp32.kicad_sch, oscillator3.2x2.5.step]
2023-10-19 fixed polarity symbol
    [bitaxeUltra.kicad_pcb, bitaxeUltra.kicad_sch]
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2023-11-19 fix GND
    [bitaxeUltra.kicad_pcb, bitaxeUltra.kicad_sch, esp32.kicad_sch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]
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2023-11-20 - added fix for #96 and #97 - beefed up vias for new SMD barrel connector - added PWR_EN pullup - added PLUG_SENSE signal to GPIO12 - Regenerated BOM - Added gerbers - Added missing 3D files
    [54-00164.STEP, bitaxeUltra BOM.xlsx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]
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2024-01-12 fixed button footprint for #113. regenerated gerbers
    [bitaxeUltra-B_Cu.gbr, bitaxeUltra-B_Mask.gbr, bitaxeUltra-B_Paste.gbr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]
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

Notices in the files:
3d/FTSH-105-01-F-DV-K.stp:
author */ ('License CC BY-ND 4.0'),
